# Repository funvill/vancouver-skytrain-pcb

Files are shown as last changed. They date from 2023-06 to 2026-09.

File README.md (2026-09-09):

# Vancouver SkyTrain PCB

A printed circuit board that is a map of Metro Vancouver's SkyTrain network,
with one addressable RGB LED per station. Based on
[Idea022 Translink Map PCB](https://blog.abluestar.com/idea022-translink-map-pcb/).

| Version | Where | What |
|---|---|---|
| **v3 (current)** | [`ai-v3/`](ai-v3/) | 200 × 109 mm board, real geography from the BC Freshwater Atlas, station positions from OpenStreetMap, 68 WS2812B LEDs (every current and under-construction station + SeaBus), XIAO controller footprint on the back, generated end-to-end from a data file |
| v2 | [`v2/`](v2/) | 100 × 83 mm schematic-style board, artwork drawn in Inkscape and imported with svg2shenzhen |
| v1 | [`v1/`](v1/) | 320 × 210 mm board with two LEDs per station (one per direction), ESP32 |

**Front** — exposed-copper water, silkscreen routes and station rings, one LED per station:

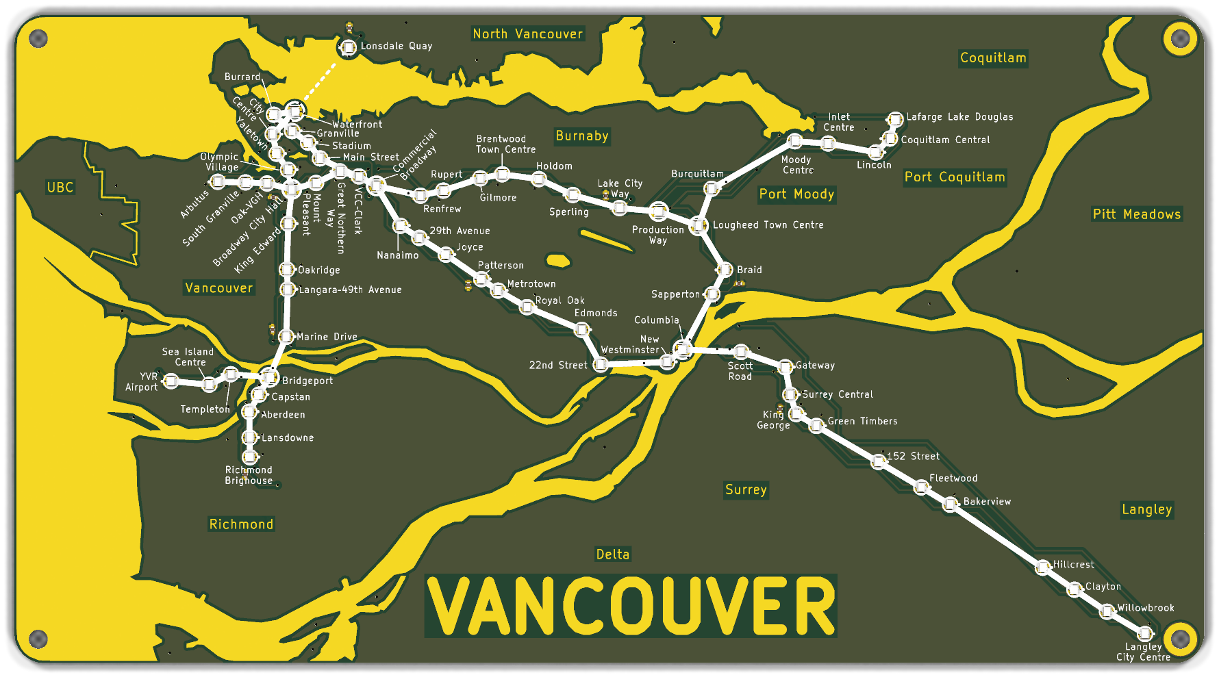
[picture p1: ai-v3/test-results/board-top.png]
v3 board, front


**Back** — XIAO controller footprint, four buttons, LED chain in/out test points, M3 mounting holes:

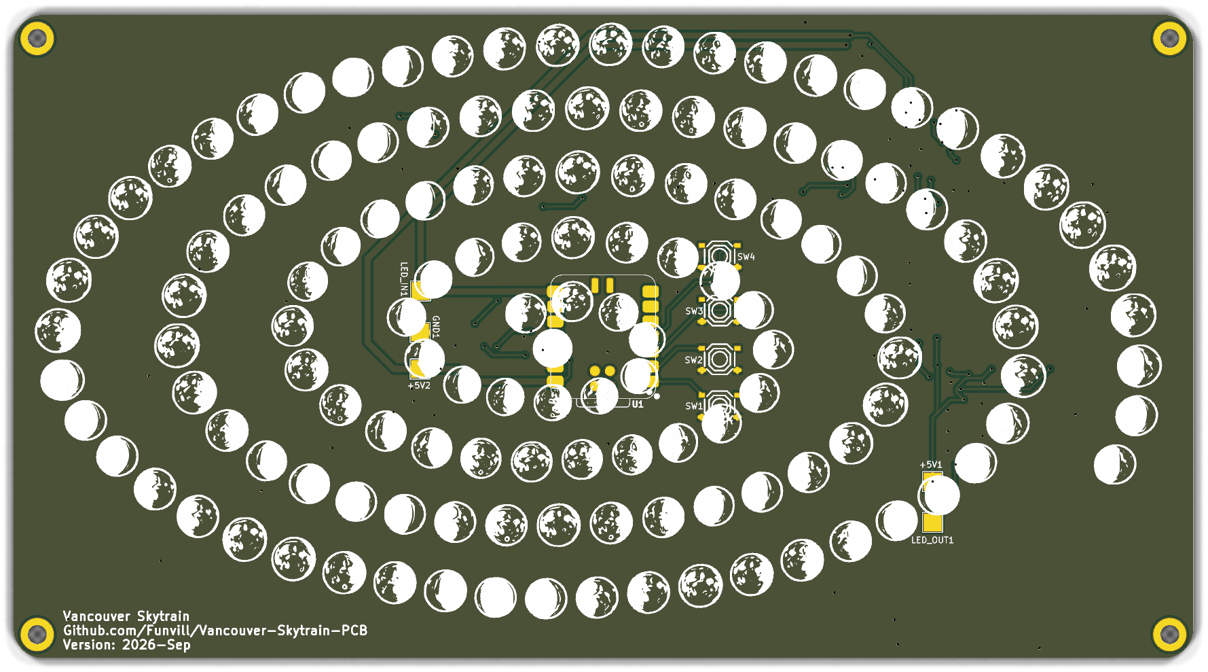
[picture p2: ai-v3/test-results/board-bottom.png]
v3 board, back


Renders are KiCad 10 `kicad-cli pcb render` output (`ai-v3/tools/render_board.py`); the
geography-only preview is `ai-v3/test-results/geo-preview.png`.

## v3 in one paragraph

Everything on the v3 board — LED placement, the exposed-copper water, the
silkscreen routes, station rings and labels, the copper city names and
wordmark — is generated from one data file, `ai-v3/input/vancouver.json`, by
the scripts in `ai-v3/tools/`. The data file is itself built from public
sources (`ai-v3/input/build_from_fwa.py`): the province's Freshwater Atlas
for land, sea, rivers and lakes; OpenStreetMap for station positions; the
province's ABMS layer for the UBC boundary. Labels are laid out by an
optimiser and then finished by hand in KiCad, and the hand edits are pulled
back into the data file so nothing is ever lost to a regeneration.

## Pipeline (v3)

All commands run from `ai-v3/tools/` unless noted. Python 3 with `shapely`,
`numpy`, `scipy`, `pillow`, `matplotlib`; KiCad 10 (its `kicad-cli` is used
for DRC and renders).

### 1. Data

```
cd ai-v3/input
python geo_fwa.py                 # (optional) preview the geography alone -> ../test-results/geo-preview.png
python build_from_fwa.py          # geography + stations + city labels + wordmark -> vancouver.json
cd ../tools
python test_vancouver_data.py     # LED count, chain, pitch, margins
```

`build_from_fwa.py` keeps every station's `label` and the `suppressed_art`
list, so it is safe to re-run after hand edits.

### 2. Labels

```
python auto_label.py                       # greedy placement + simulated annealing
python preview_map.py ../input/vancouver.json ../test-results/preview.png --collisions
python check_fit.py ../input/vancouver.json --scale 2.0 -v
```

`preview_map.py` draws the board exactly as the exporter will (matplotlib,
no KiCad); the red overlay marks collisions.

### 3. Board

```
python export_placement.py ../input/vancouver.json ../hardware --scale 2.0
python reposition_board.py ../hardware/vancouver-skytrain-pcb.kicad_pcb ../hardware/leds.csv --board 200 --height 109
python export_art.py ../input/vancouver.json ../hardware/vancouver-skytrain-pcb.kicad_pcb --scale 2.0
python render_board.py ../hardware/vancouver-skytrain-pcb.kicad_pcb ../test-results
```

`export_art.py` is idempotent: it records every block it writes (uuid → key)
in `vancouver-skytrain-pcb.kicad_pcb.art-manifest.json` and removes them
before writing fresh ones.

### 4. Hand edits in KiCad → back into the data (**import before export**)

Station labels, leader lines and copper text are ordinary `gr_text` /
`gr_line` items. Move, rotate, re-justify, retext or delete them in KiCad,
save, then:

```
python import_labels.py ../input/vancouver.json ../hardware/vancouver-skytrain-pcb.kicad_pcb
```

Each item is found by its deterministic uuid, so the import is exact:

| You did in KiCad | Lands in `vancouver.json` as |
|---|---|
| moved / rotated / re-justified a station label | `label.dx` `dy` `angle` `anchor` (`start` / `end` / `center`) |
| deleted a leader line | leader dropped (`leader` absent) |
| edited a label's text (line break, shorter name) | station `wrap` list, or `label.short` |
| moved a city name or the wordmark | `annotations[i].x` / `y` |
| deleted a piece of generated art (SeaBus dash, route segment, boundary) | key added to `suppressed_art`; the exporter skips it from then on |

**Always run `import_labels.py` before `export_art.py`** — the exporter
regenerates every label from the data file and would otherwise overwrite
the board's hand edits. `import → export` reproduces the board exactly.

## Lessons learned

See [lessons-learned.md](lessons-learned.md) — what to carry into the next
board of this kind, and the mistakes not to repeat.

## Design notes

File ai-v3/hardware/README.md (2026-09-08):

# v3 Hardware (KiCad)

Copied from the v2 project, then rewritten by the pipeline:

- **Board outline**: 150 × 150 mm, 5 mm rounded corners (was v2's 100 × 82.9 mm)
- **LED1–LED68**: moved to the station positions in `leds.csv` (generated from
  `ai-v3/input/vancouver.json` by `tools/export_placement.py`). LED index =
  ref − 1 = position in the data chain; LED1 is SeaBus, first after the shifter.
- **U1 (XIAO, back)**: centered at (75, 75); **SW1–SW4** flank it. All DNP.
- v2's stale svg2shenzhen art footprints were removed.
- **Station labels + land/water art** (F.SilkS text, F.Cu/F.Mask water,
  F.SilkS land outlines) generated directly into the board by
  `tools/export_art.py` — no Inkscape/svg2shenzhen step needed. See below.
- The coastline in `ai-v3/input/vancouver.json`'s `geo` list is hand-authored
  to resemble Vancouver's real geography (Burrard Inlet with the Port Moody
  arm, the downtown peninsula, False Creek between the Canada Line and
  Broadway corridor, the Fraser River's islands) at the level of detail v1's
  natural map used — not the coarse first-pass shapes from earlier in this
  project. Render `tools/render_board.py` output before touching `geo`
  again, so you're comparing against the current look, not an old shape.

**Render the board as images** (KiCad 9's built-in 3D renderer, top-down):

```
python render_board.py ../hardware/vancouver-skytrain-pcb.kicad_pcb ../test-results
```

Writes `board-top.png` and `board-bottom.png`. Pass `--kicad-cli` if
`kicad-cli.exe` isn't at the default `C:\Program Files\KiCad\9.0\bin\`.

Regenerate placements after any layout change:

```
cd ../input && python build_from_fwa.py      # geography + stations + city labels -> vancouver.json
cd ../tools
python export_placement.py ../input/vancouver.json ../hardware --scale 2.0
python reposition_board.py ../hardware/vancouver-skytrain-pcb.kicad_pcb ../hardware/leds.csv --board 200 --height 109
python export_art.py ../input/vancouver.json ../hardware/vancouver-skytrain-pcb.kicad_pcb --scale 2.0
```

The board is **200 × 109 mm** (`board_scale` 2.0 in `vancouver.json`: board mm =
canvas units × 2). Preview the layout without KiCad with
`python preview_map.py ../input/vancouver.json ../test-results/preview.png --collisions`.

**Hand-editing labels in KiCad.** Station labels, their leader lines and the
copper city names / wordmark are ordinary `gr_text` / `gr_line` items — move,
rotate, re-justify, retext or delete them in the PCB editor. Then pull the
edits back into the data file **before** the next `export_art.py` run (which
regenerates every label from `vancouver.json` and would otherwise overwrite
them):

```
python import_labels.py ../input/vancouver.json ../hardware/vancouver-skytrain-pcb.kicad_pcb
```

Each item is found by the deterministic uuid the exporter gave it, so the
import is exact: position/rotation/justification → `label.dx/dy/angle/anchor`,
a deleted leader line → `leader: false`, an edited text → the station's
`wrap` (or `label.short`), a moved city name → `annotations[i].x/y`. A
pre-edit copy of the board and data lives in `backups/` (and git tag
`v3-pre-label-edit`).

Run them in that order (placement first, art second — art positions itself
relative to the current LED footprint locations). `export_art.py` is
idempotent: it tracks every block it writes in
`vancouver-skytrain-pcb.kicad_pcb.art-manifest.json` and removes them before
writing fresh ones, so re-running after an edit to `vancouver.json` never
leaves stale or duplicated art behind.

## Station labels, route lines, and land/water art

`export_art.py` writes native KiCad graphics directly into the `.kicad_pcb`
(not through svg2shenzhen — that path is for hand-drawn art; ours is
generated straight from the same station/geo data as everything else),
styled after TransLink's own "Future Rapid Transit Network" map — one water
colour, filled parks, labelled rivers/municipalities, and a distinct look
for future/under-construction line segments:

- **Route lines** (`route_blocks`) — every line segment from
  `vancouver.json`'s `lines` as an F.SilkS `gr_line`, 1.0 mm wide. A segment
  with either endpoint `future: true` (Broadway Extension, Surrey–Langley
  Extension) is drawn as real **dashed segments** (`dash_points()`) instead
  of one solid line — matching the reference map's "future line" styling.
  Important: KiCad's `(stroke (type dash))` line-*style* property is an
  **editor display hint only** — it does not survive to plotted/fab output
  (SVG export, 3D render, gerbers all flatten it to solid), confirmed by
  testing both here. A genuinely dashed silkscreen line has to be built
  from literal short solid segments with real gaps, which is what
  `dash_points()` does.
- **Station names** — `gr_text` on F.SilkS, same position/rotation math as
  the SVG preview (`citymap.label_box`), 0.15 mm stroke at 1.2 mm. Names
  longer than 13 characters are set on **two lines** (split at the
  official en-dash, else at the middle space — `citymap.display_lines`;
  override per station with `"wrap": [...]` or `"wrap": false`), so the
  abbreviated `short` forms are no longer used on the board. Every label
  anchor sits `LABEL_STANDOFF` (1.9 mm) from the LED centre, clear of the
  pad and ring. A label with `"leader": true` is floated out to its dx/dy
  and joined to the LED by a 0.15 mm hairline — `auto_label.py` uses that
  as a last resort for stations with no clean spot beside the pad, and
  prefers one angle per corridor so the eye tracks a single direction.
- **Station rings** (`station_ring_blocks`) — a silk ring behind every LED
  (r 1.25) so the station reads as circle-on-line; interchanges (`
  "interchange": true`) get a heavier r 1.55 ring. Routes are 1.5 mm.
- **Map furniture** — `geo` entries of `"type": "line"` are plain silk
  polylines with an optional `"dash"` of `dash` / `dot` / `dashdot`
  (SeaBus ferry route, the 49th-parallel border, legend swatches); an
  annotation with `"copper": true` is exposed-copper lettering (F.Cu +
  F.Mask, the gold "VANCOUVER" wordmark from v2).
- **Water** (sea, False Creek, Fraser River) — a filled polygon on **F.Cu**
  with a matching filled polygon on **F.Mask**, so the soldermask opens
  over the copper and it reads as bare copper (gold with ENIG) against the
  black board — the same technique v1 used
  (`v1/input/natrual/natrual/map.kicad_pcb`), generated instead of
  hand-drawn.
- **Land — islands**: thin F.SilkS outline only, no fill (the board
  substrate itself *is* the land, so these just need a boundary).
  **Land — parks**: outline *plus* a 45° diagonal hatch fill
  (`citymap.hatch_fill()`, 1.6 mm spacing) — the single-ink silkscreen
  stand-in for the reference map's solid green park colour. `hatch_fill()`
  is a general scan-line polygon fill (even-odd rule, works on concave
  shapes) so it's reusable for any future city's parks too.
- **Annotations** (`annotation_blocks`) — small F.SilkS text (legend
  labels, CANADA / USA at the border) or copper text (the wordmark). No
  municipality names or water-body labels are printed, by request.

### Station positions and geography: OpenStreetMap

Station positions and `vancouver.json`'s water shapes come from
OpenStreetMap via `../input/build_from_osm.py` — real station nodes, the
real shoreline (smoothed), the Fraser and Pitt rivers, and the large
lakes. The board is **150 × 86.2 mm**, the aspect of the lat/lon frame
(Point Grey → Langley, North Shore → below Langley) at 3.1 mm/km; water
runs to the board edge (0.4 mm copper-to-edge, corners pulled inside
the 5 mm radius) — there is no border. Earlier revisions used
TransLink's schematic PDF and then v1's hand-drawn map; see
`../input/README.md`. Deliberately not literal:

- Runs whose real spacing is under the LED pitch (downtown, Richmond,
  Sea Island, Coquitlam) are spread outward along their own direction,
  then any remaining too-close pair is separated symmetrically. The
  pitch floor is **3.3 mm**: LED footprints rotate to aim DOUT at the
  next LED, and two diagonal neighbours' pads need that to keep 0.2 mm.
- A station the smoothing leaves inside water (a river-bank station) is
  nudged onto land, as the real map shows it; every LED then gets a
  2.2 mm clearance disk carved out of the copper water.
- The "VANCOUVER" wordmark is exposed-copper lettering placed on land
  (Delta), at the first candidate spot clear of water and track.

Routes are one solid 1.0 mm style for every segment, built or not.
- The Broadway Extension and Surrey–Langley Extension aren't on the
  current-network PDF (not built yet), so those 14 stations are
  extrapolated by continuing each real corridor's traced direction and
  spacing from its last real station.
- Every station's label **direction** (which side of the dot the name
  sits on) is hand-tuned in `vancouver.json`, not traced — the PDF gives
  dot positions, not a reusable label layout. Real station spacing is
  tight enough in a few spots (the airport branch, the Coquitlam bend,
  New Westminster/Columbia/22nd Street) that some labels sit close to a
  neighbour's dot or to the water fill; `check_fit.py` calls these out
  as `label-geo` (expected for coastal stations) vs. real overlaps
  (`label-label`/`label-dot`/`label-line`, hand-fixed one at a time).

### Keeping copper art DRC-clean: `citymap.prepared_geo`

A water/land shape sized for the map doesn't know where the LEDs are, so
raw coordinates from `vancouver.json` will happily overlap LED pads,
bridge the board edge, or trip solder-mask-bridge/clearance rules.
`citymap.prepared_geo(city, scale, avoid_pts)` fixes this once, and
`render_map.py`, `check_fit.py`, and `export_art.py` all call it — so the
SVG preview, the label-collision report, and the physical board always
agree:

1. `densify()` — long polygon edges get intermediate vertices (so a strait
   crossing an LED cluster mid-edge, not just at a vertex, still gets
   caught).
2. `repel()` — any vertex within `keepout` of an LED is pushed away from it.
3. `clamp_to_board()` — vertices are kept inset from the board edge (copper
   needs edge clearance even where the art is meant to visually "bleed" to
   the frame, like the coastline running to the top of the board).
4. `simplify()` (open shapes only, e.g. rivers) — collapses the extra
   densify() vertices back down once they're no longer needed, so a long
   straight run doesn't turn into dozens of tiny render segments.

For **rivers** specifically (drawn as a chain of rectangles, one per
polyline segment, since they have width but no fill), `export_art.py`
adds a final per-segment safety check
(`citymap.poly_point_min_dist`, `RIVER_SAFE_FLOOR`): any rectangle that
still ends up too close to an LED after all of the above is *dropped*
rather than emitted un-safe, and the drop is printed, not silent. On this
board the Fraser River crosses the same tight diagonal corridor the Expo
Line's SkyBridge stations occupy, so several of its segments are
intentionally omitted — the gaps read as the river passing under a
bridge, which is accurate. If you widen station spacing or move the river
line, re-run `export_art.py` and check its printed drop list.

**Known cosmetic-only DRC warnings** (verified non-blocking,
`kicad-cli pcb drc`, 2026-08-30): a handful of `silk_overlap` /
`silk_over_copper` warnings where a station label or a park/island
outline crosses the water fill or another silk element (e.g. Aberdeen's
label crossing the Lulu Island outline). These are `warning`-severity
(KiCad reports them as "Local override" candidates) and are the expected
look of a coastal transit map with exposed-copper water — no station near
the water was going to avoid overlapping it. `clearance` and
`copper_edge_clearance` (the categories that would actually risk a fab
reject or a short) are both **0** after the fixes above.

## Still manual (open in KiCad)

1. **Rotate LEDs for chain routing** — `leds.csv` has the suggested rotation
   (DOUT toward the next chain index); the script deliberately does not touch
   rotation because pad angles must be rewritten by KiCad itself.
2. **Verify U1 orientation**: USB-C must face the bottom board edge (Y+).
3. **Schematic**: v2's sheet is still the source. Confirm the 68-LED chain
   order matches `leds.csv`, add the **74AHC1G125** (C23654) data buffer at
   5 V + 330 Ω series R, decoupling (100 nF per 2 LEDs + 2 × 22 µF bulk), and
   re-annotate/re-sync with the board.
4. Route the data chain and power/ground pours (front + back).
5. DRC, then JLCPCB fab outputs (gerbers / BOM / CPL). Board finish: black
   soldermask, white silk, ENIG (so the exposed-copper water reads gold).

Pre-existing, not caused by the above (present since the v2 copy — schematic
has no routing yet): `unconnected_items`, `shorting_items` (unrouted nets),
`lib_footprint_mismatch` (library version drift), `courtyards_overlap`
(U1/button placement), one `text_height` warning on U1's hidden reference
field, and a `solder_mask_bridge` pair on nearly every LED footprint's own
pads (the XL-1615 library footprint's pads sit close together at that
package size — a library fix, not something the map art caused).

Firmware lives in `../firmware` (PlatformIO, XIAO RP2040, builds clean);
its index tables (`include/firmware_tables.h`) are generated by the same
export — regenerate both together.

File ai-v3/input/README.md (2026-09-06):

# Input data

- **`vancouver.json`** — the city data file the whole `ai-v3/tools/`
  pipeline reads (schema documented in `../docs/plan.md`).
- **`build_from_osm.py`** — **the current source of station positions and
  geography.** Builds `vancouver.json` from OpenStreetMap: real station
  nodes, the `natural=coastline` ways (land is on the left of a coastline
  way — that's how sea and land are told apart), the Fraser/Pitt river
  centrelines buffered where the coastline stops, and only the large
  named lakes (Burnaby, Deer, Trout, Como, Lost Lagoon…). The shoreline
  is smoothed (morphological open/close + simplify) so it reads clean at
  3 mm/km. The frame is a lat/lon box (Point Grey → past Langley, North
  Shore → below Langley) and the board takes its aspect: **150 × 86.2 mm**,
  water running to the board edge. Raw Overpass responses are cached in
  `osm/` (queries listed at the bottom of the script) so it runs offline.
  Run it, then `../tools/auto_label.py`, then the hardware pipeline with
  `reposition_board.py --board 150 --height 86.2`.
- `build_from_v1.py` — superseded: built the map from the v1 project's
  hand-drawn natural map, kept for reference (its `v1_*.json` inputs too).
- **`skytrain-network-map.pdf`** — TransLink's official current-network
  map. It was the tracing source for an earlier revision (below); its
  schematic page is 1.26:1 where the real region is ~2:1, so everything
  south of Broadway came out stretched and the Fraser turned into a
  45° band — which is why the v1 natural map replaced it.

## (Superseded) How `vancouver.json` was traced from the PDF

Station positions and land/water/park shapes are **not hand-drawn** — they
were extracted from the PDF's actual vector content (text + path data),
not eyeballed from a rendered image. Rerun this pipeline after swapping in
a newer PDF (a future TransLink map revision, or the Broadway/Surrey–Langley
version once it exists):

```
pip install pdfplumber pymupdf shapely   # one-time
python match_stations.py     # words.json + circles.json -> station_coords.json
python build_geo.py          # geo_shapes.json -> geo_canvas.json (water/park polygons)
python build_vancouver_json.py   # writes ../input/vancouver.json
```

1. **`match_stations.py`** — `pdfplumber` extracts every text label's exact
   (x, y); `pymupdf` (`fitz`) extracts every station-dot circle (drawn as a
   small filled circle, colour-coded by line — teal `(0,0.61,0.78)` =
   Canada Line, medium blue `(0,0.37,0.67)` = Expo Line, yellow
   `(1,0.83,0)` = Millennium Line, navy `(0,0.21,0.37)` = an
   interchange/major-hub marker). Each station gets one reliable,
   document-unique anchor word (`ANCHOR` in `match_stations.py`) and is
   matched to its nearest circle. Diagonal/angled labels near line
   junctions (Commercial–Broadway, Lougheed Town Centre, Sapperton, Lake
   City Way, VCC–Clark…) came out as garbled individual characters from
   pdfplumber (the angled text confuses its word-grouping) — those were
   resolved by hand against the known real line topology (station order,
   even spacing along a row/diagonal) instead of by text matching; see
   `build_vancouver_json.py`'s `PDF_XY` table for the final values used.
2. **`build_geo.py`** — the PDF draws land as opaque cream polygons over a
   full-page water-blue background, the opposite of our board (water is
   the explicit exposed-copper shape, land is just the bare board). This
   script extracts every land polygon's vector points, unions them with
   Shapely, and subtracts that union from the page rectangle — the
   remainder *is* the water, matching the PDF exactly, including the
   Fraser's arms and Sea Island / Lulu Island falling out as holes
   automatically (no river/island shape was hand-drawn or guessed).
   Park polygons are extracted the same way and kept separate for the
   hatch-fill treatment.
3. **`build_vancouver_json.py`** — converts every PDF-point coordinate to
   the 0–100 canvas with a uniform affine transform (a fixed margin inset
   + independent-axis scale to fill the square board — the real network
   is wider than it is tall, so this is the one deliberate distortion;
   everything else preserves the source proportions exactly). The Broadway
   Extension and Surrey–Langley Extension stations aren't on this PDF (not
   built yet) — they're extrapolated by continuing each real corridor's
   traced direction and spacing from its last real station, not traced
   from a source.
4. Label **angle/anchor** (which side of the dot the name sits on) still
   has to be tuned per station in `vancouver.json` afterward — the PDF
   trace gives the *dot* position, not a usable label layout, since the
   official map's real labels are hand-placed by a cartographer and
   pdfplumber's per-character extraction for angled ones isn't reliable
   enough to reuse directly. `../tools/auto_label.py` automates this: it
   brute-forces every angle in `[-90, 90]` (angles outside that range
   render the glyphs upside-down/mirrored in KiCad — rotation is rigid,
   there's no auto-flip for readability) crossed with `start`/`end`
   anchor for each station `check_fit.py` flags a real collision on
   (`label-label`/`label-dot`/`label-line` — not `label-geo`, which is
   expected for a station that's genuinely next to water or a park), and
   keeps the option with the fewest collisions. Re-run it after any
   position change; `check_fit.py -v` on its own shows what's left.

`words.json` / `circles.json` / `geo_shapes.json` / `geo_canvas.json` /
`station_coords.json` are the intermediate extraction artifacts (kept for
inspection/debugging) — none of them are hand-authored, and none should be
edited directly; edit `vancouver.json` instead, or rerun the pipeline
against a new PDF.

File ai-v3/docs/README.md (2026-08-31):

# Vancouver SkyTrain PCB — Version 3 (ai-v3)

Documentation for the third revision of the SkyTrain LED map PCB.

## Goal for v3

A **smaller, square board** showing the **iconic (schematic-style) SkyTrain map**, with:

- The same WS2812B addressable RGB LEDs used in v2 (XL-1615RGBC-WS2812B-1, LCSC C5349954)
- One LED per station, including **all new and under-construction stations**
  (Capstan, the Broadway Extension, and the Surrey–Langley Extension)
- **No controller populated on the board.** Instead, a Seeed Studio **XIAO footprint on the
  back** of the board so any XIAO-family module (RP2040, ESP32-C3, SAMD21, nRF52840…) can be
  soldered on.

## Documents

| File | Contents |
|---|---|
| [project-review.md](project-review.md) | Review of v1 and v2 in their current state — what was built, what works, what's unfinished |
| [v3-recommendations.md](v3-recommendations.md) | Recommendations and a step-by-step plan for building v3 |
| [station-list.md](station-list.md) | Complete station list (including future stations), interchange notes, and a proposed LED chain order |
| [plan.md](plan.md) | Implementation plan (assumption tests → board → firmware → reusable pipeline) |
| [fit-report.md](fit-report.md) | Results of the 100 mm text-fit test — verdict: 135 × 135 mm recommended |

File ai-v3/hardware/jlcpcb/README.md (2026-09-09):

# JLCPCB outputs

Generated from `vancouver-skytrain-pcb.kicad_pcb` / `.kicad_sch` with KiCad 10
`kicad-cli` (see the commands at the bottom). Regenerate after any board change.

| File | Upload as |
|---|---|
| `vancouver-skytrain-pcb-gerbers.zip` | **Gerber file** on the order page — 9 layers (F/B Cu, Paste, Mask, Silk + Edge.Cuts, Protel extensions), Excellon drill `.drl` (PTH + NPTH merged) and the drill map |
| `bom-jlcpcb.csv` | **BOM** on the SMT assembly page — `Comment, Designator, Footprint, LCSC Part #` |
| `cpl-jlcpcb.csv` | **CPL / pick-and-place** — `Designator, Mid X, Mid Y, Layer, Rotation` (mm, KiCad position-file convention) |

Assembly covers the **68 WS2812B LEDs** (C5349954, top side) and the **8 × 10 µF
0402 capacitors** (C52923). Everything else is not placed by JLC:

- **SW1–SW4** are DNP in the schematic.
- **U1** (Seeed XIAO) is a module soldered by hand.
- Test points and mounting holes have no part.

`pos-raw.csv` and `bom-raw.csv` are the untouched `kicad-cli` outputs the two
JLC files were derived from.

**Check on the JLC page before ordering:** the LED rotation. JLC's part
library orientation for C5349954 may differ from the KiCad footprint's by a
constant; the placement preview shows pin 1 — if every LED is off by the same
angle, correct the `Rotation` column by that constant (all LEDs share the
same footprint, so one offset fixes all 68).

Board: 200 × 109 mm, 2 layers, ENIG recommended (the exposed-copper water is
the artwork — HASL works but reads silver), any soldermask colour; the design
was previewed in dark green with white silkscreen.

```
kicad-cli pcb export gerbers vancouver-skytrain-pcb.kicad_pcb -o jlcpcb/gerbers/ \
    -l F.Cu,B.Cu,F.Paste,B.Paste,F.SilkS,B.SilkS,F.Mask,B.Mask,Edge.Cuts \
    --subtract-soldermask --no-x2 --no-netlist --check-zones
kicad-cli pcb export drill vancouver-skytrain-pcb.kicad_pcb -o jlcpcb/gerbers/ \
    --format excellon --excellon-units mm --generate-map --map-format gerberx2
kicad-cli pcb export pos vancouver-skytrain-pcb.kicad_pcb -o jlcpcb/pos-raw.csv \
    --format csv --units mm --side both --exclude-dnp
kicad-cli sch export bom vancouver-skytrain-pcb.kicad_sch -o jlcpcb/bom-raw.csv \
    --fields "Reference,Value,Footprint,LCSC Part,LCSC,DNP" --group-by "Value,Footprint,LCSC Part,LCSC" --exclude-dnp
python ../tools/make_jlcpcb.py      # -> bom-jlcpcb.csv, cpl-jlcpcb.csv, gerbers zip
```

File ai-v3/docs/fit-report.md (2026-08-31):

# V3 Text-Fit Test Report

**Question:** does the iconic map with all 68 station names fit on a 100 × 100 mm board?

**Answer: No — as expected. Full station names need ≥ 120 mm.**

> **DECISION (user, 2026-08-30): board is 150 × 150 mm**, map extended west to cover the
> Point Grey peninsula. The layout was re-tuned for 150 mm (network shifted 5 mm east for
> the peninsula, Surrey leg turns south at Bakerview, Coquitlam branch stepped down-left)
> and now checks **0 collisions with full names at 1.2 mm text**. Geography added: sea
> outline (Burrard Inlet + Port Moody arm + English Bay + Georgia Strait), False Creek,
> Fraser River, Sea Island and Lulu Island outlines, and parks (Stanley, Pacific Spirit,
> Queen Elizabeth, Central, Green Timbers, Burnaby Lake, Lafarge Lake).
> On the physical board: water = soldermask-opening or copper-pour treatment, parks =
> silkscreen hatch — final layer mapping is chosen in the artwork-export task.

## Method

The reusable pipeline (`ai-v3/tools/`) models every station label as a rotated rectangle
(char width = 0.7 × text height, KiCad-stroke-font-like metrics) and counts collisions:
label↔label, label↔route-line, label↔LED-dot, and label-off-board. Board size scales;
text height does not (silkscreen has a fab minimum), which is exactly why bigger boards
fix text crowding. Reference silkscreen heights: **1.0 mm = JLCPCB minimum**, **1.2 mm =
comfortably readable**.

Layout under test: `ai-v3/input/vancouver.json` — 67 stations + SeaBus = 68 LEDs,
octilinear iconic geometry, validated by `test_vancouver_data.py` (counts, shared
interchanges, 45°/90° segments, ≥ 2.5 mm LED spacing).

## Results (collision counts, lower = better)

| Board | 1.0 mm full | 1.0 mm short | 1.2 mm full | 1.2 mm short |
|---|---|---|---|---|
| 100 mm | 5 | 1 | **16** | 4 |
| 120 mm | **0** | 0 | 4 | 1 |
| 135 mm | 0 | 0 | **1** | 0 |
| 150 mm | 0 | 0 | 0 | 0 |

Rendered previews (collisions highlighted red): `ai-v3/test-results/map-*.svg`,
back side: `ai-v3/test-results/back-side.svg`.

## Findings

1. **100 mm fails for full names.** At readable text (1.2 mm) there are 16 collisions and
   five labels run off the board (Coquitlam Central, Vancouver City Centre, Oakridge,
   Sea Island Centre, YVR). The user's expectation that the board must grow is confirmed.
2. **Label geometry matters as much as board size.** The first layout iteration had
   collisions that *no* board size fixed (labels crossing a parallel line 3 mm away scale
   with the board, staying in collision). Fix that worked: move the **Canada Line from
   x=16 → x=19 mm** so the west-Broadway diagonal labels clear it, put King Edward's and
   Broadway–City Hall's labels on the south-east diagonal, and anchor the airport-branch
   labels to the left. After that, collisions became purely text-size-vs-board-size.
   *Lesson encoded for future cities: keep ≥ 7 mm between a vertical line and any station
   to its west whose label points down-right.*
3. **120 mm works at fab-minimum text** (1.0 mm, full names, zero collisions) but 1.0 mm
   white-on-black silk is squint territory.
4. **135 mm works at comfortable text** (1.2 mm) with a single residual collision:
   "29th Avenue" clips the tail of "Great Northern Way–Emily Carr" (the longest name on
   the network, 29 chars ≈ 24 mm of silk). Using its short form "Gt Northern Way" — or a
   future two-line label feature — clears it: **zero collisions**.
5. **150 mm is fully clean** with all full names at 1.2 mm.
6. **Back side is a non-issue at any size.** XIAO SMD courtyard (19.8 × 23 mm incl.
   margin) centered with USB-C toward the bottom edge, 4 × 5.1 mm buttons, 74AHC1G125 and
   bulk caps all fit with huge margins on even the 100 mm board. The board is all-SMD, so
   front LEDs and back parts can overlap in Z with no conflict; only via placement needs
   care during routing. USB-C sits ~57 mm from the bottom edge on a 135 mm board — a
   cable reaches it fine for desk use; for wall mounting, a keyhole slot must avoid the
   board center.

## Recommendation

- **Board: 135 × 135 mm**, text 1.2 mm, full names everywhere except
  "Gt Northern Way" (short form). Nicely, `v2/input/map3.svg` was already drawn at
  150 × 150 — the artwork tradition supports a board in this class, and 135 mm keeps it a
  step smaller while staying collision-free.
- Fallback if cost matters: 120 × 120 mm with 1.0 mm text (JLC minimum) — fits, but
  print a paper mockup first to judge readability.
- 100 × 100 mm remains viable only as a "dots + interchange names" novelty variant; the
  data file already carries `short` names if that route is ever wanted.

## Assumptions verified / still open

| Assumption | Status |
|---|---|
| 68 LEDs (67 stations + SeaBus) covers the full 2029 network | ✔ verified by data test (counts + interchange dedupe) |
| Iconic octilinear layout fits a square canvas | ✔ rendered, visually recognizable as the SkyTrain map |
| 100 mm too small for names | ✔ confirmed (16 collisions @ 1.2 mm) |
| ≥ 2.5 mm LED-to-LED spacing everywhere | ✔ min pitch 3.0 mm (Sapperton–Braid) |
| XIAO + buttons + shifter fit on back | ✔ trivially |
| Land/water geometry co-exists with map | ✔ rendered (inlet, False Creek, Fraser, Sea Island); final art treatment (mask openings vs. silk) still to be chosen |
| Fab: 1.2 mm text / 0.15 mm stroke OK for JLC white silk | ⚠ to confirm against JLC capabilities page at order time |
| Surrey–Langley station names final | ⚠ working names — re-verify before silk |

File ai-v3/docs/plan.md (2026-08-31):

# SkyTrain PCB v3 Implementation Plan

> **For agentic workers:** REQUIRED SUB-SKILL: Use superpowers:subagent-driven-development (recommended) or superpowers:executing-plans to implement this plan task-by-task. Steps use checkbox (`- [ ]`) syntax for tracking.

**Goal:** A 100 × 100 mm (size to be confirmed by the text-fit test) square PCB of the iconic Vancouver SkyTrain map — one WS2812B per station including all future stations, XIAO footprint (DNP) centered on the back with USB-C down, level shifter, SeaBus LED, iconic land/water geometry, white silkscreen on black soldermask.

**Architecture:** A city-agnostic Python pipeline (`ai-v3/tools/`) turns a per-city data file (`ai-v3/input/vancouver.json` — lines, stations, coordinates, geography) into (a) rendered SVG previews with collision/fit reports, (b) svg2shenzhen-ready artwork layers, and (c) LED placement + firmware index tables. The KiCad board consumes the pipeline output. The pipeline is the reusable component for future cities; only the JSON data file is city-specific.

**Tech Stack:** Python 3 (stdlib only — no pip deps, so it runs anywhere), SVG, KiCad 8, svg2shenzhen (Inkscape extension), PlatformIO + FastLED.

## Global Constraints

- Board: square, starting hypothesis **100 × 100 mm**; expand only if the text-fit test proves names don't fit (test heights: 1.0 mm fab minimum, 1.2 mm comfortable).
- Finish: **white silkscreen on black soldermask** (black board). Route lines rendered as silkscreen and/or exposed copper; art must read in white-on-black.
- LEDs: **XL-1615RGBC-WS2812B-1 (LCSC C5349954)**, one per station, plus **1 SeaBus LED** — **68 LEDs total** (67 unique stations + SeaBus).
- Stations: full 2029 network — Expo 32 (incl. 8 Surrey–Langley, ~2029), Millennium 23 (incl. 6 Broadway Extension, ~2027), Canada 17 (incl. Capstan), minus 5 shared interchange stations.
- Controller: **no controller populated**. Seeed **XIAO SMD footprint on the back, DNP, centered, USB-C pointing down** (toward the bottom board edge). Buttons also on back, **DNP**.
- Level shifter: **74AHC1G125** (SOT-23-5, LCSC C23654) on the LED data line, powered at 5 V, as in v1.
- Geography: iconic land/water shapes (Burrard Inlet, downtown peninsula, Fraser River, Sea Island) on the artwork layers.
- Reusability: tools must not hard-code Vancouver anything; all city data lives in the input JSON.

---

## Phase A — Assumption tests (before any board work)

### Task 1: City data schema + Vancouver data file

**Files:**
- Create: `ai-v3/input/vancouver.json`
- Create: `ai-v3/tools/citymap.py` (shared loader/model)
- Test: `ai-v3/tools/test_vancouver_data.py`

**Interfaces:**
- Produces: `citymap.load(path) -> City` where `City` has `.stations` (dict id → Station with `name, short, x, y, future, label` fields), `.lines` (list of Line with `id, name, color, paths` = lists of station ids), `.extras` (SeaBus), `.geo` (water/land polygons), `.canvas_mm`.
- JSON schema (city-agnostic):

```json
{
  "city": "vancouver",
  "canvas_mm": 100,
  "lines": [
    {"id": "expo", "name": "Expo Line", "color": "#005DAA",
     "paths": [["waterfront", "burrard", "..."], ["columbia", "scott-road", "..."]]}
  ],
  "stations": {
    "waterfront": {"name": "Waterfront", "x": 16, "y": 10,
                    "label": {"angle": 0, "anchor": "end"}, "future": false}
  },
  "extras": [{"id": "seabus", "name": "SeaBus", "x": 20, "y": 5}],
  "geo": [{"name": "burrard-inlet", "type": "water", "points": [[0,0], [100,0], "..."]}]
}
```

- [ ] **Step 1: Write failing validation test** (`test_vancouver_data.py`): 68 LEDs total (stations + extras); every path id resolves; the 5 interchange stations appear in ≥ 2 lines but exist once; every consecutive station pair is octilinear (horizontal, vertical, or 45°); all coordinates within canvas with ≥ 3 mm margin; every station has a non-empty name.
- [ ] **Step 2: Run it** — fails (no data file).
- [ ] **Step 3: Author `vancouver.json`** — all 67 stations + SeaBus with iconic octilinear coordinates on a 100 mm canvas, per-station label angle/anchor, `short` names for long stations, geography polygons.
- [ ] **Step 4: Run test — passes.**
- [ ] **Step 5: Commit** (`git -c user.name="SWS-Chipkin" -c user.email="sws-dev@chipkin.com" commit`).

### Task 2: SVG renderer

**Files:**
- Create: `ai-v3/tools/render_map.py`
- Test: rendered output inspected + self-checks in `test_vancouver_data.py` extended

**Interfaces:**
- Consumes: `citymap.load()`.
- Produces: `render(city, scale=1.0, text_h=1.2, use_short=False) -> str (svg)`; CLI `python render_map.py vancouver.json out.svg --scale 1.0 --text 1.2`.
- SVG in mm units: black board rect, water polygons, route polylines (line colors for preview; final art is white), station dots + 1.6 × 1.5 mm LED body outline, rotated labels, XIAO 17.8 × 21 mm outline centered (back-side ghost), board outline.

- [ ] **Step 1:** Implement renderer.
- [ ] **Step 2:** Render at scale 1.0 and view in browser — layout is recognizable as the SkyTrain map, no gross errors.
- [ ] **Step 3:** Commit.

### Task 3: Fit checker (the actual assumption test)

**Files:**
- Create: `ai-v3/tools/check_fit.py`
- Output: `ai-v3/test-results/fit-report.md`, `ai-v3/test-results/map-*.svg`

**Interfaces:**
- Consumes: `citymap.load()`, same geometry code as renderer.
- Produces: `check(city, scale, text_h, use_short) -> FitResult(collisions: list, board_mm: float)`; label boxes modeled as rotated rectangles (char width = 0.7 × height + stroke), collision = label∩label, label∩other-line, label∩other-dot via SAT polygon intersection.

- [ ] **Step 1:** Unit test SAT intersection with two known rects (overlap / no overlap).
- [ ] **Step 2:** Implement checker.
- [ ] **Step 3:** Run the experiment matrix: {100 mm, 120 mm, 135 mm, 150 mm} × {1.0, 1.2 mm text} × {full, short names}. Record collision counts.
- [ ] **Step 4:** Write `fit-report.md` with the matrix, the verdict on 100 mm, and the recommended board size. Render an annotated SVG (collisions highlighted red) for the chosen candidates.
- [ ] **Step 5:** Commit.

### Task 4: Back-side fit check (XIAO + buttons + level shifter)

**Files:**
- Modify: `ai-v3/tools/render_map.py` (back-side view mode)
- Output: `ai-v3/test-results/back-side.svg`

- [ ] **Step 1:** Render back view: XIAO-SMD courtyard (17.8 × 21 mm + 1 mm) centered, USB-C edge toward board bottom, 4 button courtyards (5.1 × 5.1 mm), 74AHC1G125, bulk caps; confirm no conflict with front LED thru-hole-free zone (all SMD, so only via keepouts matter).
- [ ] **Step 2:** Note reset/boot access and USB-C cable clearance in the report.
- [ ] **Step 3:** Commit.

**Decision gate:** present fit-report to the user; board size is locked here.

---

## Phase B — Board (after size is locked)

### Task 5: Pipeline outputs for KiCad

**Files:**
- Create: `ai-v3/tools/export_placement.py` — emits `leds.csv` (ref, x, y, rotation, station id) with chain order = the station-list order; emits `firmware_tables.h` (per-line index arrays) from the same data.
- Create: `ai-v3/tools/export_art.py` — emits svg2shenzhen-layered SVG (`Edge.Cuts`, `F.SilkS` = names + land outlines in white, `F.Mask` openings for copper route lines, `B.SilkS` credits block).
- Test: round-trip check — 68 rows in `leds.csv`, chain neighbors ≤ 25 mm apart (data-line routing sanity).

### Task 6: KiCad project

- Copy v2 KiCad project to `ai-v3/hardware/`; keep local libs (`C5349954-led`, `Seeed Studio XIAO`, `C318884-button`).
- Schematic: 68 LEDs chained, 74AHC1G125 buffer (input from XIAO D-pin, OE tied active, 5 V supply), 330 Ω series R at buffer output, 1 × 100 nF per 2 LEDs + 2 × 22 µF bulk, XIAO symbol (DNP), 4 buttons (DNP) to XIAO GPIOs with no external pull-ups (internal), SeaBus LED last in chain.
- Import `leds.csv` positions (KiCad "Position from file" / pcbnew script), import art via svg2shenzhen, place XIAO centered on B.Cu USB-C down, route 5 V/GND pours front+back, route data chain.
- DRC clean; JLCPCB production files (gerbers, BOM, CPL) with black soldermask + white silk + ENIG selected.

### Task 7: Firmware

- Copy `v1/firmware` → `ai-v3/firmware`; `platformio.ini`: `board = seeed_xiao_rp2040`.
- Replace index tables with generated `firmware_tables.h`; `NUM_LEDS = 68`; add `FastLED.setMaxPowerInVoltsAndMilliamps(5, 1500)`; keep demo animation; buttons on internal pull-ups for mode/brightness.
- Build passes; (bench test after boards arrive).

### Task 8: Reusable-pipeline extraction (after Vancouver ships)

- Move `ai-v3/tools/` to repo-root `tools/` (or its own repo) unchanged; document the JSON schema in `tools/README.md`; prove reuse by drafting a second city data file stub.

## Self-Review notes

- Spec coverage: 100 mm test (Task 3), expansion expectation (Task 3 matrix), new lines (Task 1 data), one LED/station (Task 1 test), XIAO back/DNP/centered/USB-down (Tasks 4, 6), buttons DNP (Tasks 4, 6), SeaBus (Task 1), level shifter (Task 6), land geometry (Tasks 1, 2, 5), white-on-black (Tasks 2, 5, 6), reusable components (schema-driven tools, Task 8). ✔
- Types consistent: `citymap.City` consumed by render/check/export. ✔

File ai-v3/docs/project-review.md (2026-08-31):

# Project Review — state as of 2026-08-30

Review of the repository (`vancouver-skytrain-pcb`) before starting version 3.

## Repository layout

```
v1/       Shipped first version (Teardown 2024 era). Hardware + firmware + inputs.
v2/       In-progress second version. Hardware + input SVGs. No firmware folder.
ai-v3/    New — empty except for these docs.
```

Uncommitted work: `v2/input/map3.svg` has significant local changes (+460 lines) that are
not committed. This appears to be the in-progress **150 × 150 mm square iconic map**
drawing and is directly relevant to v3 — it should be committed (or moved into `ai-v3/input/`)
before it gets lost.

---

## V1 — shipped board

**Hardware** (`v1/hardware/vancouver-skytrain-pcb/`, KiCad 8):

- Realistic/geographic map style ("natural"), rounded-rectangle board.
- **127 × XL-1010RGBC-WS2812B** (1.0 × 1.0 mm addressable RGB, LCSC C5349953) — one LED
  *per station per travel direction* (e.g. "Waterfront north" and "Waterfront south" are
  separate LEDs), which is why the count is roughly double the station count. Index 126 is
  the SeaBus.
- **On-board controller: ESP32-WROOM-32E** with 3.3 V LDO (UR133AG), a **74AHC1G125**
  buffer used as the 5 V level shifter for the LED data line, reset/boot buttons, Phoenix
  screw-terminal power input, and a programming header.
- 136 × 1 µF 0402 decoupling caps — essentially one per LED.
- Fun detail worth keeping: 126 test points shaped like bugs, one per LED.

**Firmware** (`v1/firmware/vancouver-skytrain/`, PlatformIO + FastLED):

- Demo mode written for Teardown 2024: multiple "trains" per line advance station-by-station
  with fading, per-line speeds. Lines covered: Expo (both directions, both branches),
  Millennium (both directions, **already includes the six Broadway Extension stations**
  through Arbutus), Canada Line (both directions, both branches), SeaBus.
- Note: `platformio.ini` targets **Raspberry Pi Pico** (`board = pico`), not the ESP32 that
  is on the v1 board. So the firmware in the repo as-is was last built for an RP2040 — this
  is actually convenient for v3 if a XIAO RP2040 is used (same chip family, same FastLED
  setup, just change the board to `seeed_xiao_rp2040`).
- Hard-coded LED-index-to-station tables. `NUM_LEDS = 130`, brightness capped at 32/255.

**What v1 proves:** the svg2shenzhen art pipeline works, the WS2812B chain at ~127 LEDs
works, the demo animation works, and JLC production files (BOM/CPL/gerbers) were generated
successfully.

---

## V2 — in progress

**Hardware** (`v2/hardware/`, KiCad):

- Board outline: **100 × 82.9 mm** rounded rectangle (not square).
- **68 × XL-1615RGBC-WS2812B-1** (1.6 × 1.5 mm, LCSC C5349954) placed — the larger 1615
  package instead of v1's tiny 1010. One LED **per station** this time (68 ≈ 67 unique
  future-network stations + SeaBus — see [station-list.md](station-list.md)).
- **Seeed Studio XIAO RP2040 footprint (SMD variant) already placed on the back (B.Cu)** —
  v2 already adopted the "no on-board controller, XIAO on the back" architecture that v3
  wants. Local libraries exist for XIAO RP2040 and SAMD21, in both DIP and SMD variants.
- 4 push buttons (C318884), 7 × 0402 caps, 5 test points, logos.
- Schematic exists (`vancouver-skytrain-pcb.kicad_sch`).
- Last commit: "part placement" (Nov 2025). No routing/production files yet, no firmware
  folder.

**Inputs** (`v2/input/`):

- `transitmap.svg` — stylized iconic map with 68 station circles (novelty styling, "$0.25"
  fare marks, "VANCOUVER" title).
- `map3.svg` — **150 × 150 mm square** drawing with proper svg2shenzhen layers
  (`Edge.Cuts`, `F.Cu`, `F.Mask`, `F.SilkS`, `B.SilkS`) plus a `station.names` layer, 68
  station markers. **Uncommitted local changes.** This is effectively the starting point
  for v3's artwork.

**What's missing in v2:** power/decoupling design is thin (7 caps for 68 LEDs vs. one-per-LED
in v1), no level-shifter decision recorded, board is not square, no routing, no firmware, and
the newest map work is uncommitted.

---

## Key observations going into v3

1. **v2 already made the two big architectural decisions v3 asks for** — one LED per
   station and a XIAO footprint on the back. v3 is best treated as *finishing v2 on a
   smaller square outline*, not a from-scratch redesign.
2. **The LED part decision is effectively made**: XL-1615RGBC-WS2812B-1 (C5349954), with
   library, 3D model, and 68 placements already in v2. "Same LEDs" should mean this part.
   (v1's 1010 part is fiddlier to hand-rework and gains nothing here.)
3. **The station data already exists twice** — in v1 firmware tables and in the v2 SVG
   markers — but nowhere as a single authoritative list. v3 should create one (see
   [station-list.md](station-list.md)) and generate both the firmware table and the LED
   placement from it.
4. **The firmware is 90 % reusable.** Change the board target to the XIAO, drop from
   two-LEDs-per-station to one, renumber the index tables, and the Teardown demo runs on v3.
5. **Two known electrical gaps to close** (both solved in v1, dropped in v2): LED data-line
   level shifting from a 3.3 V microcontroller to 5 V LEDs, and per-LED (or per-group)
   decoupling.

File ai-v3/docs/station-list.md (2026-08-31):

# Station List & Proposed LED Chain — v3

One LED per unique station. Network as of 2026 **plus stations under construction**:
Capstan (opened Dec 2024), the Broadway Extension (6 stations, ~2027), and the
Surrey–Langley Extension (8 stations, ~2029).

**Totals:** Expo 32 + Millennium 23 + Canada 17 = 72 line-stations − 5 shared
(Commercial–Broadway, Lougheed Town Centre, Production Way–University, Waterfront,
Broadway–City Hall) = **67 unique stations**, + 1 SeaBus marker = **68 LEDs**.
This matches the 68 markers already drawn in `v2/input/map3.svg`.

Chain order below is a proposal: contiguous per line, so firmware tables are simple ranges.
Interchange LEDs are owned by the first line that reaches them; later lines reference the
existing index (marked ↩).

## Expo Line (LED 0–31)

| LED | Station | Notes |
|-----|---|---|
| 0 | Waterfront | Interchange: Canada Line, SeaBus |
| 1 | Burrard | |
| 2 | Granville | |
| 3 | Stadium–Chinatown | |
| 4 | Main Street–Science World | |
| 5 | Commercial–Broadway | Interchange: Millennium |
| 6 | Nanaimo | |
| 7 | 29th Avenue | |
| 8 | Joyce–Collingwood | |
| 9 | Patterson | |
| 10 | Metrotown | |
| 11 | Royal Oak | |
| 12 | Edmonds | |
| 13 | 22nd Street | |
| 14 | New Westminster | |
| 15 | Columbia | Branch point |
| 16 | Sapperton | Production Way branch |
| 17 | Braid | |
| 18 | Lougheed Town Centre | Interchange: Millennium |
| 19 | Production Way–University | Interchange: Millennium |
| 20 | Scott Road | King George branch |
| 21 | Gateway | |
| 22 | Surrey Central | |
| 23 | King George | |
| 24 | Green Timbers | **Future (Surrey–Langley, ~2029)** |
| 25 | 152 St | **Future** |
| 26 | Fleetwood | **Future** |
| 27 | Bakerview–166 St | **Future** |
| 28 | Hillcrest–184 St | **Future** |
| 29 | Clayton | **Future** |
| 30 | Willowbrook | **Future** |
| 31 | Langley City Centre | **Future** |

## Millennium Line (LED 32–49, + 5 shared/↩)

| LED | Station | Notes |
|-----|---|---|
| 32 | Arbutus | **Future (Broadway Ext., ~2027)** — western terminus |
| 33 | South Granville | **Future** |
| 34 | Oak–VGH | **Future** |
| 35 | Broadway–City Hall | **Future on Millennium**; interchange: Canada Line (LED shared, owned here or by Canada — pick one) |
| 36 | Mount Pleasant | **Future** |
| 37 | Great Northern Way–Emily Carr | **Future** |
| 38 | VCC–Clark | Current western terminus |
| ↩ 5 | Commercial–Broadway | shared with Expo |
| 39 | Renfrew | |
| 40 | Rupert | |
| 41 | Gilmore | |
| 42 | Brentwood Town Centre | |
| 43 | Holdom | |
| 44 | Sperling–Burnaby Lake | |
| 45 | Lake City Way | |
| ↩ 19 | Production Way–University | shared with Expo |
| ↩ 18 | Lougheed Town Centre | shared with Expo |
| 46 | Burquitlam | |
| 47 | Moody Centre | |
| 48 | Inlet Centre | |
| 49 | Coquitlam Central | |
| 50 | Lincoln | |
| 51 | Lafarge Lake–Douglas | Eastern terminus |

## Canada Line (LED 52–66, + 2 shared/↩)

| LED | Station | Notes |
|-----|---|---|
| ↩ 0 | Waterfront | shared with Expo |
| 52 | Vancouver City Centre | |
| 53 | Yaletown–Roundhouse | |
| 54 | Olympic Village | |
| ↩ 35 | Broadway–City Hall | shared with Millennium (post-extension) |
| 55 | King Edward | |
| 56 | Oakridge–41st Avenue | |
| 57 | Langara–49th Avenue | |
| 58 | Marine Drive | |
| 59 | Bridgeport | Branch point |
| 60 | Templeton | Airport branch |
| 61 | Sea Island Centre | |
| 62 | YVR–Airport | |
| 63 | Capstan | **New (opened Dec 2024)** — Richmond branch |
| 64 | Aberdeen | |
| 65 | Lansdowne | |
| 66 | Richmond–Brighouse | |

## Extras

| LED | Marker | Notes |
|-----|---|---|
| 67 | SeaBus (Burrard Inlet crossing) | v1 had this (index 126); optionally animate as a slow ferry blink between Waterfront and Lonsdale Quay |

## Notes for implementation

- **Verify names against TransLink before silkscreen** — the Surrey–Langley working names
  (Green Timbers, 152 St, Fleetwood, Bakerview–166 St, Hillcrest–184 St, Clayton,
  Willowbrook, Langley City Centre) could still change before opening.
- v1 firmware already contains the Broadway Extension stations in its Millennium tables,
  so its animation logic needs no new concepts — only renumbering to the single-LED-per-
  station indices above.
- Physical chain routing may prefer a different order than the logical one — that's fine.
  Keep the *logical* table in one CSV/JSON file and generate both the firmware header and a
  cross-check against the KiCad reference designators from it.

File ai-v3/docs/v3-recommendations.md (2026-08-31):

# V3 Recommendations

Target: a smaller **square** board, iconic map, one WS2812B per station (all new stations
included), no controller populated — a **XIAO footprint on the back** instead.

## 1. Treat v3 as "v2 finished on a square outline"

v2 already has the right architecture (68 LEDs, XIAO-on-back, iconic map). Recommended
starting move:

1. Create `ai-v3/hardware/` by copying the v2 KiCad project, and `ai-v3/input/` by moving
   `v2/input/map3.svg` there (commit it first — it currently has uncommitted changes).
2. Keep the v2 local libraries as-is: `C5349954-led` (XL-1615RGBC-WS2812B-1),
   `Seeed Studio XIAO`, `C318884-button`.

## 2. Board size — decide first, everything else follows

`map3.svg` is drawn at 150 × 150 mm; v2's board was 100 × 82.9 mm. Options:

| Size | Pros | Cons |
|---|---|---|
| **100 × 100 mm (recommended)** | JLCPCB/PCBWay cheap-prototype sweet spot; noticeably smaller than v1; iconic map with 68 stations fits comfortably | Station-name silkscreen gets small (~1 mm text) — still readable but near the limit |
| 150 × 150 mm | map3.svg needs no rescaling; roomy labels | Not really "smaller"; higher fab cost |
| 70–80 mm square | Very cute, coaster-sized | 68 × 1615 LEDs + names get very tight; Expo/Millennium shared corridor gets congested; probably drop station names |

Recommendation: **100 × 100 mm**, scale map3.svg down 2/3 in Inkscape (svg2shenzhen carries
mm through faithfully). Verify minimum silkscreen text height (JLC: ≥ 1 mm height,
≥ 0.15 mm stroke) after scaling; if names don't fit, keep names for interchanges/termini
only and put the full legend on the back silkscreen.

## 3. XIAO footprint on the back

- Use the **XIAO-*-SMD variant** (castellated pads, module lies flat) on `B.Cu`, as v2
  already does. Also add the two **B.Cu keep-out / courtyard** considerations:
  - Nothing on the front side directly opposite the module if you ever want the DIP
    (through-hole header) variant as a fallback — consider placing both footprints
    overlapped (SMD pads + DIP holes), a common trick that supports either mounting.
- **Pin budget is tiny and that's fine**: 5 V, GND, one data pin, plus 2–4 GPIOs for
  buttons. All XIAO family members pin out 5V/GND/3V3 identically, so the board stays
  controller-agnostic (RP2040, ESP32-C3 for WiFi clock/real-time data, nRF52840…).
- Orient the module so the **USB-C connector faces (and slightly overhangs or sits at) the
  board edge** — this is the power inlet and programming port. The XIAO's reset/boot
  buttons face away from the board when surface-mounted, so they stay accessible, but add
  labelled test points or two small pads for RESET/BOOT anyway.
- If the board will hang on a wall, USB-C at the **bottom edge** hides the cable best.

## 4. Electrical design (close the two v2 gaps)

- **Level shifting.** The XIAO drives data at 3.3 V; WS2812B at 5 V wants VIH ≥ 0.7 × VDD
  = 3.5 V. It often works anyway, but don't ship marginal: reuse v1's proven
  **74AHC1G125** (SOT-23-5, C23654) powered at 5 V as a data buffer. It costs pennies and
  removes the #1 flicker risk.
- **Decoupling.** 7 caps for 68 LEDs (v2) is too thin. The XL-1615 is small; a pragmatic
  middle ground is **one 100 nF–1 µF 0402 per 2–4 LEDs** distributed along the chain, plus
  **2 × 22 µF bulk** near the XIAO 5 V feed. (v1 used one 1 µF per LED — fine too, but
  doubles placement count.)
- **Power budget.** 68 LEDs × 60 mA worst case ≈ 4 A — far beyond USB. Not a hardware
  problem if firmware caps it: keep v1's brightness limit and add FastLED's
  `setMaxPowerInVoltsAndMilliamps(5, 1500)`. At demo brightness (32/255) the whole board
  draws well under 500 mA. Make 5 V and GND pours wide (front pour + back pour) since the
  chain snakes the whole board.
- **Series resistor** (~300 Ω) on the data line at the buffer output, and keep v1's
  bug-shaped test points if there's room — they were a signature detail.

## 5. LED chain and station data

- **One authoritative station list** drives everything — see
  [station-list.md](station-list.md): 67 stations + SeaBus = **68 LEDs**, matching the 68
  markers already in map3.svg/v2.
- Chain order recommendation: route the data chain **line by line** (Expo including both
  branches → Millennium → Canada Line including both branches → SeaBus) so firmware line
  tables are contiguous ranges instead of scattered indices. Interchange stations get **one
  LED, owned by one line**, and the other line's table simply references that index (v1's
  firmware already works this way for Production Way/Lougheed).
- Mark future stations (Broadway Extension opens ~2027, Surrey–Langley ~2029, already
  under construction) with a distinct silkscreen ring so the map is honest today and
  correct later. Firmware can skip/dim them in "current network" mode.

## 6. Artwork / fab finish

- Keep the svg2shenzhen pipeline from v1/v2 (`Edge.Cuts`, `F.Cu`, `F.Mask`, `F.SilkS`,
  `B.SilkS` layers in map3.svg are already set up for it).
- Silkscreen is single-colour, so line identity must come from geometry: the classic trick
  (used in v1) is drawing the route lines as **exposed copper (F.Cu + F.Mask openings)** so
  they render as gold/silver traces, with silkscreen for names and water/background. With
  ENIG + black soldermask this looks excellent. Optional: order variants with different
  soldermask colours per batch.
- Put the credits, LED index legend, and firmware URL/QR code on the back silkscreen around
  the XIAO.

## 7. Firmware

- Copy `v1/firmware` to `ai-v3/firmware`, change `platformio.ini` to
  `board = seeed_xiao_rp2040` (it already targets the `raspberrypi` platform, so this is a
  one-line change), set `NUM_LEDS = 68`, and regenerate the index tables from the station
  list. The two-directional-LEDs concept collapses to one index per station; keep the
  multi-train animation by fading a train through the single per-station LED.
- Wire the 2–4 buttons (v2 already placed 4) to mode/brightness/speed/next-line, active-low
  with internal pull-ups — no external resistors needed.
- Generate the station table from `station-list.md` (or a CSV) with a small script rather
  than hand-numbering 68 entries again.

## 8. Process / repo hygiene

1. **Commit `v2/input/map3.svg` now** (its 460-line local change is the newest map work).
2. Structure `ai-v3/` as `hardware/`, `firmware/`, `input/`, `docs/` (matching v1).
3. Before ordering: run DRC, generate JLC BOM/CPL like v1's `production/` folder, and
   sanity-check the LED chain order visually (KiCad 8 can highlight the DIN/DOUT net path).
4. Order a **5-board prototype**; hand-solder one XIAO to validate before committing to a
   panel run.

## Open questions (decide before layout)

1. **Board size** — 100 × 100 mm recommended; confirm.
2. **Station names on front?** At 100 mm they're marginal; interchanges-only is the safe call.
3. **Include SeaBus LED** (v1 had it; the 68th marker suggests v2 kept it) — keep?
4. **Buttons: how many and which face?** Back-side buttons keep the front clean but are
   awkward wall-mounted; edge-adjacent front buttons are friendlier.
5. **Mounting**: M3 holes in corners, or a single keyhole slot on the back for wall hanging?
6. **Which XIAO ships as the "reference" module** — RP2040 (cheapest, matches existing
   firmware) or ESP32-C3 (enables live TransLink data / clock modes later)? The footprint
   supports both; the choice only affects documentation and default firmware.

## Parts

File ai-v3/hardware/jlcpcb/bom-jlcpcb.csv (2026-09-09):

Comment | Designator | Footprint | LCSC Part #
XL-1615RGBC-WS2812B | LED1,LED2,LED3,LED4,LED5,LED6,LED7,LED8,LED9,LED10,LED11,LED12,LED13,LED14,LED15,LED16,LED17,LED18,LED19,LED20,LED21,LED22,LED23,LED24,LED25,LED26,LED27,LED28,LED29,LED30,LED31,LED32,LED33,LED34,LED35,LED36,LED37,LED38,LED39,LED40,LED41,LED42,LED43,LED44,LED45,LED46,LED47,LED48,LED49,LED50,LED51,LED52,LED53,LED54,LED55,LED56,LED57,LED58,LED59,LED60,LED61,LED62,LED63,LED64,LED65,LED66,LED67,LED68 | LED-SMD_4P-L1.6-W1.5_XL-1615RGBC-WS2812B-1 | C5349954
10uF,10V,X5R | ROW0,ROW1,ROW2,ROW3,ROW4,ROW5,ROW6,ROW7 | C_0402_1005Metric | C52923

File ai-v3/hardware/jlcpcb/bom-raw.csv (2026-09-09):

Reference | Value | Footprint | LCSC Part | LCSC | DNP
+5V1,+5V2,GND1,LED_IN1,LED_OUT1 | TestPoint | TestPoint:TestPoint_Pad_3.0x3.0mm
LED1-LED68 | XL-1615RGBC-WS2812B | C5349954-led:LED-SMD_4P-L1.6-W1.5_XL-1615RGBC-WS2812B-1 | C5349954
ROW0-ROW7 | 10uF,10V,X5R | Capacitor_SMD:C_0402_1005Metric |  | C52923
U1 | XIAO-RP2040-DIP | Seeed Studio XIAO:XIAO-RP2040-SMD

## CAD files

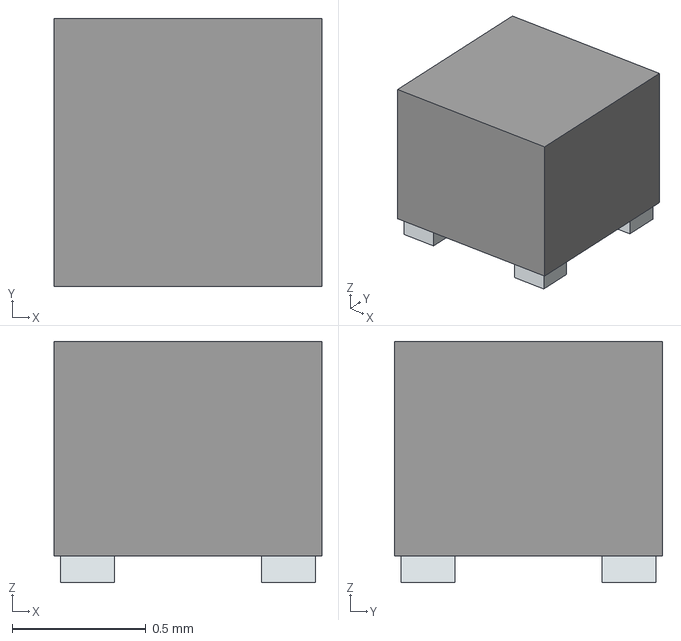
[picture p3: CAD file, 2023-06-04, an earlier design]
v1/hardware/vancouver-skytrain-pcb/XL-1010RGBC-WS2812B.stp
1.00 x 1.00 x 0.9 mm
Pins

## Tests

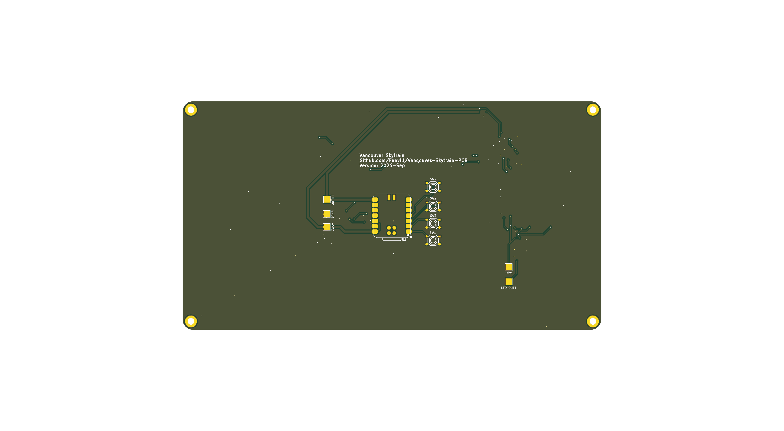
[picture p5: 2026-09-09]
ai-v3/test-results/board-bottom-transparent.png

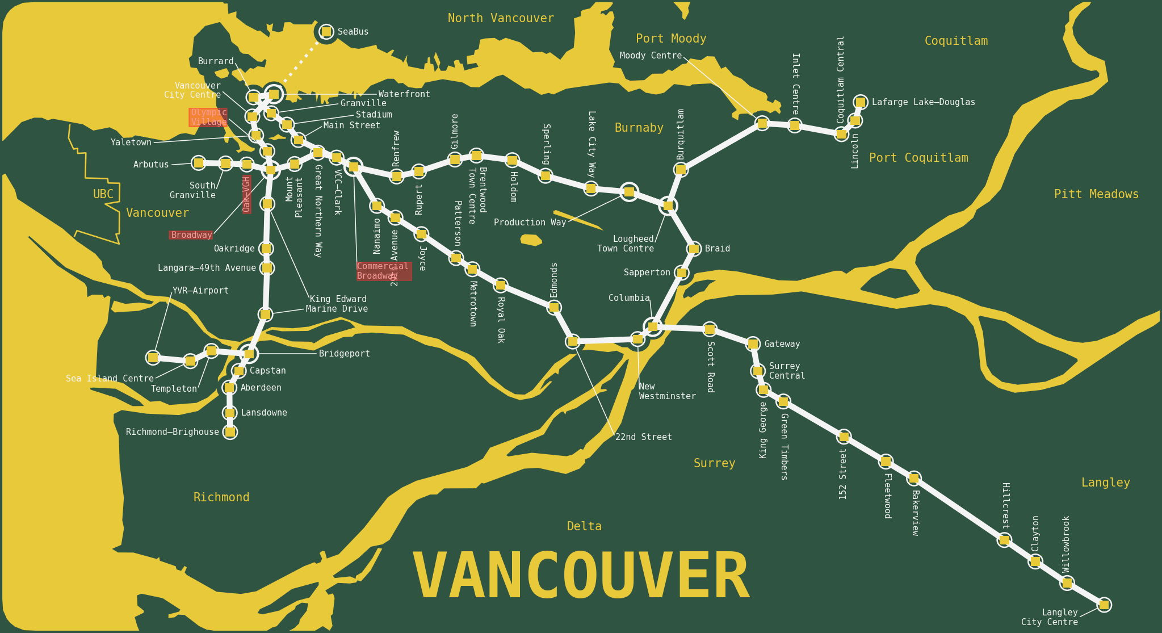
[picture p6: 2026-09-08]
ai-v3/test-results/preview.png

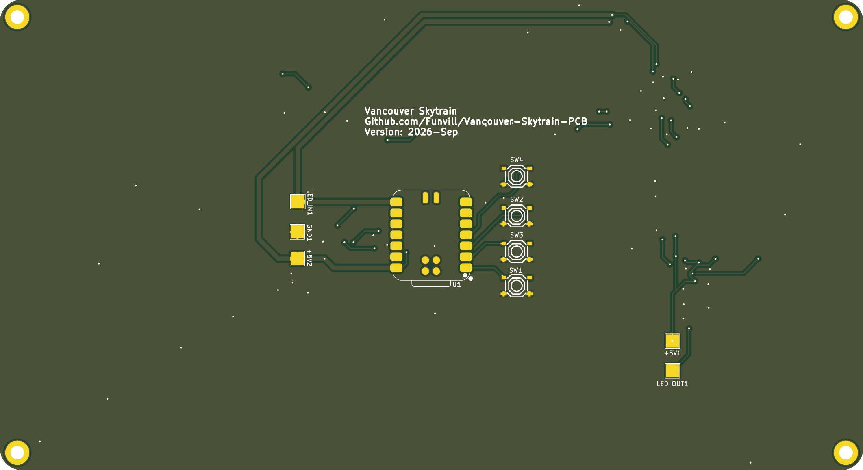
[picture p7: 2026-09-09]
ai-v3/test-results/board-bottom-mask.png

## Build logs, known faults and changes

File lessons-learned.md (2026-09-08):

# Lessons learned — building a transit-map LED PCB

Collected while building v3 of the Vancouver SkyTrain board. Written for
the next board of this kind (another city, another network), so each
lesson says what to do, not just what went wrong.

## 1. Get the landmass right first, on its own, before anything touches the PCB

The single biggest time sink of this project was geography. Five
successive sources were tried before the shape was right:

| Attempt | Source | Why it failed |
|---|---|---|
| 1 | Hand-authored polygons "resembling" Vancouver | Invented coastline; every review found something wrong |
| 2 | TransLink's schematic network map (PDF, vector-traced) | A schematic is not a map: its page is 1.26:1 where the region is 2:1, so everything south of Broadway was stretched and the Fraser became a 45° band; it also draws no coastline where it doesn't need one, so "the left edge should end in water" had no data behind it |
| 3 | The v1 project's hand-drawn "natural" map | Better shape, but a hand drawing: squeezed north–south, station layout not geographic, and it had to be registered to the board by fitting dots in a PNG |
| 4 | OpenStreetMap coastline via Overpass | Correct where it exists — but in this region OSM's `natural=coastline` stops at Burrard Inlet; the Fraser's arms are `natural=water` riverbank polygons that were never loaded, so Sea Island, Lulu Island and the whole estuary collapsed into land |
| 5 | **BC Freshwater Atlas (provincial 1:20k hydrography, WFS)** | Worked first time |

What made #5 work is worth generalising:

- **Prefer sources that give polygons, not lines.** Assembling coastline
  *lines* into land/sea faces (polygonize + orientation votes) is where
  the OSM attempt went wrong. The FWA gives land (watershed groups end at
  the coast → sea = frame − land), rivers and lakes all as polygons; there
  was nothing to assemble.
- **Prefer the national / provincial mapping agency over crowd-sourced
  data for water.** Look for a WFS with a bbox parameter (BC:
  `openmaps.gov.bc.ca/geo/pub/wfs`; most provinces/states/countries have
  an equivalent). Cache the raw responses in the repo so the build runs
  offline and is reproducible.
- **Make a standalone geography render** (`geo_fwa.py`) and get it
  approved before wiring it into the board pipeline. Iterating on the
  shape through KiCad renders costs minutes per round; matplotlib costs
  seconds.
- **Simplify deliberately, not by accident.** A morphological open/close
  (`buffer(-d).buffer(2d).buffer(-d)`) plus `simplify()` removes nooks;
  filling river islands below a size threshold and dropping bay tips that
  are mostly outside the frame keeps the picture clean. Keep lakes by a
  *name whitelist* — an area threshold lets 10 ha ponds in.
- **Check the obvious landmarks by eye**: the airport island, the river
  reaching the sea, the big lakes. Every one of those was missing at some
  point and no checker caught it; a human did.

## 2. Use real station positions, then bend them only where physics demands

Station positions came, in order, from a schematic, a hand drawing and
finally OSM nodes (`railway=station` + `station=subway`). Real positions
put stations on the correct side of rivers automatically — "Surrey
Central is in the water" is a symptom of a bad source, not something to
patch.

The only justified distortion is the LED pitch: downtown stations are
~500 m apart, which is 1.6 mm at 3.1 mm/km. Spread them along their own
line direction, then run a global pairwise separation, and record the
floor as a constant with the reason next to it. **The floor is 3.3 mm,
not the 2.5 mm the package suggests**: LED footprints rotate to aim DOUT
at the next LED, and two diagonal neighbours' pads overlap at 2.8 mm.
Found by DRC after the layout looked fine.

## 3. Size the board to the map's aspect, not the other way round

A square board for a 2:1 region wastes half the area and pushes the map
scale down until labels stop fitting. Decide the frame (lat/lon box)
first, derive the board size from it at the largest width the fab and
budget allow, and treat "leave a blank band" as a warning sign. Going
from 150 mm square to 200 × 109 mm raised the scale 40 % and solved more
label problems than any algorithm did.

## 4. Labels: the tight cluster decides everything — plan for it

Downtown (six stations inside 1 km, three lines crossing) is where every
labelling scheme broke. What eventually held:

- One shared text height (1.1 mm, 0.14 mm stroke — a 1:8 ratio keeps the
  stroke font's counters open), a fixed standoff from the LED, two-line
  wrapping at the name's en-dash instead of abbreviations, a "beside the
  line" candidate so labels can run along a corridor, and leader lines
  as a last resort.
- A checker that models everything on the board — other labels with a
  breathing gap, pads (own and others'), routes including the label's
  own segment beyond the standoff, leaders vs everything, silk furniture,
  copper text — because every unmodelled thing became a real overlap.
- **Greedy placement does not converge in a cluster**; a repair loop
  cycled forever. Simulated annealing over all labels found joint layouts
  the greedy pass couldn't, and even that left a handful for a human.
  Budget for a hand pass and make it round-trip safe (next lesson).
- Some things are not label problems: "Vancouver City Centre" and
  "Granville" are 300 m apart; no layout algorithm fixes that, a bigger
  board does.

## 5. Make hand edits survive regeneration — deterministic ids + an importer

The generated board is edited by hand in KiCad; the generator regenerates
it. Without a round trip, one of them always loses. What worked:

- Every generated item gets a **deterministic uuid** (`uuid5(namespace,
  key)`, keys like `label:waterfront`), and the exporter keeps a manifest
  of uuid → key so it can remove exactly what it wrote last time
  (idempotent regeneration, verified by running it twice and checking for
  duplicate uuids).
- An **importer** finds each item on the board by uuid and writes the
  human's changes back into the data (position, rotation, justification,
  text, deleted leaders). Things the human *deleted* are recorded as a
  `suppressed_art` list the exporter honours.
- Prove it with an import → export comparison on the real board: 0 of 99
  text items differing is the bar.

And the mistake that made this urgent: the user had started editing in
KiCad while the generator was still being run. `git add` swept their
edits into a commit, a regeneration overwrote them on disk, and a
"refresh the backup" step overwrote the backup too. Git had the edits.
**Take the backup before the first regeneration, never overwrite a backup,
and tag the commit.**

## 6. Model the fab's reality, not the editor's

- KiCad's stroke `type dash` line style is an **editor display hint**; it
  does not survive to gerbers, SVG export or 3D render. Draw dashes as
  real short segments.
- Text angles outside [−90°, 90°] render upside-down; rotation is rigid.
- KiCad's bold stroke font is ~10 % wider than a 0.85 × size-per-character
  estimate; the wordmark walked into a river because of it. Measure once
  from a render and put the factor in the code.
- Bare-copper "water" needs an F.Cu polygon **and** the same polygon on
  F.Mask; keep it 0.4 mm from the edge (and inside the corner radius) and
  ≥ 2 mm from every pad — carve clearance disks in the data, and repel
  edges again at export time. A real coastline puts stations *inside*
  water (ferry terminals, river banks); nudge those onto land.
- `silk_over_copper`, `silk_overlap` and `solder_mask_bridge` DRC warnings
  are the price of this aesthetic; `clearance`, `copper_edge_clearance`
  and `shorting_items` are not negotiable. Say which is which in the
  README so the next person doesn't panic (or ignore the wrong one).
- A newer KiCad silently upgrades the file format on save; an older
  `kicad-cli` then fails with "Failed to load board". Pin the CLI to the
  newest install.

## 7. Process lessons

- **Verify against the source, not against the previous fix.** Two rounds
  were spent adding a "missing" peninsula that the source map never
  showed. Re-read the source before patching a mismatch.
- **Sub-agent design critiques were worth it**: an independent
  composition / cartography / labelling review produced the list that
  drove the whole redesign (water to the edge, thin uniform routes,
  station rings, wordmark on land, drop the legend).
- **Keep every generated intermediate in the repo** (cached WFS/Overpass
  responses, station tables, preview PNGs). Builds stay reproducible and
  reviewers can see what changed.
- **Write the "what's wrong with this picture" checklist down**: river
  reaches the sea, airport island present, big lakes present, all
  stations on land, no label on bare copper, wordmark on land, nothing
  in the corner radius. Run it by eye on every render.
- **Automate the screenshot.** `kicad-cli pcb render` (and the matplotlib
  preview) after every change meant problems were seen the same minute
  they were made.

## 8. Reusing this for another city

The pipeline is city-agnostic below `vancouver.json`. For a new city you
need: (a) a lat/lon frame and board width in `geo_fwa.py`'s successor,
(b) polygon hydrography for the region (agency WFS first, OSM
`natural=water` second), (c) station lat/lon (OSM nodes, checked by eye),
(d) the line definitions and LED chain order, (e) a pitch floor for the
LED package and footprint rotation you use. Then: geography preview →
approve → data build → `auto_label` → `preview_map` → hand pass in KiCad
→ `import_labels` → verification list → render.

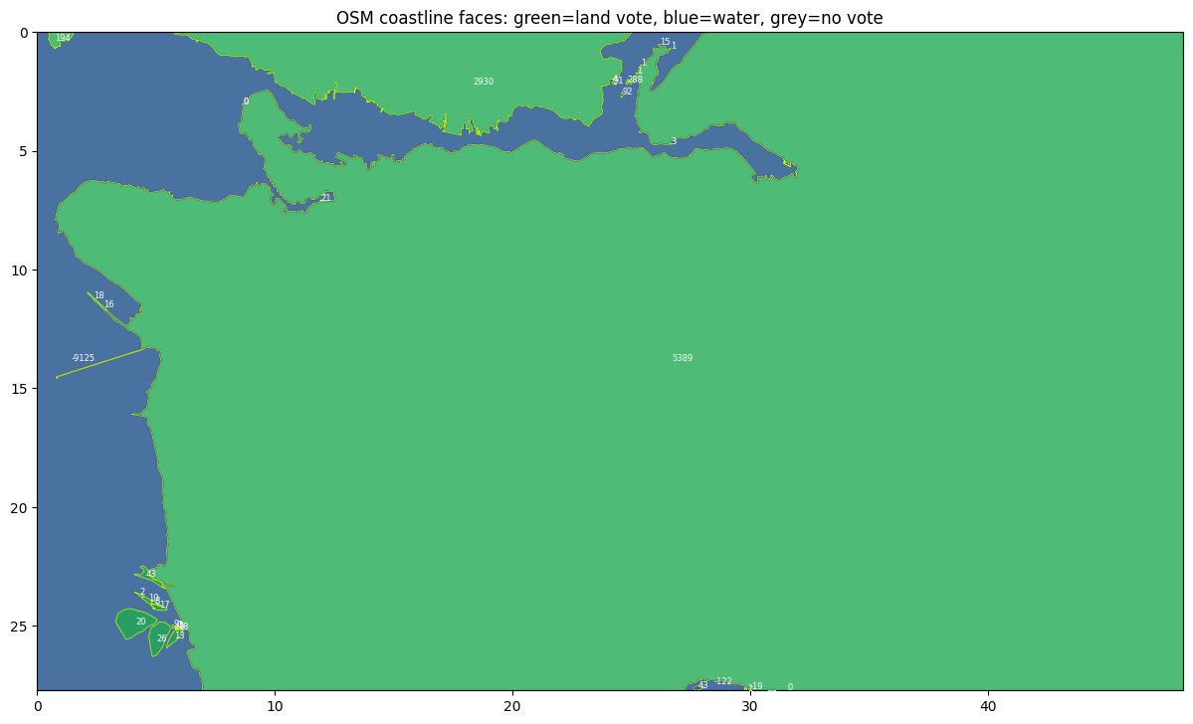
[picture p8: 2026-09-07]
ai-v3/test-results/geo-debug-faces.png

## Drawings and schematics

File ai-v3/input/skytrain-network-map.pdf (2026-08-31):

# SkyTrain Network

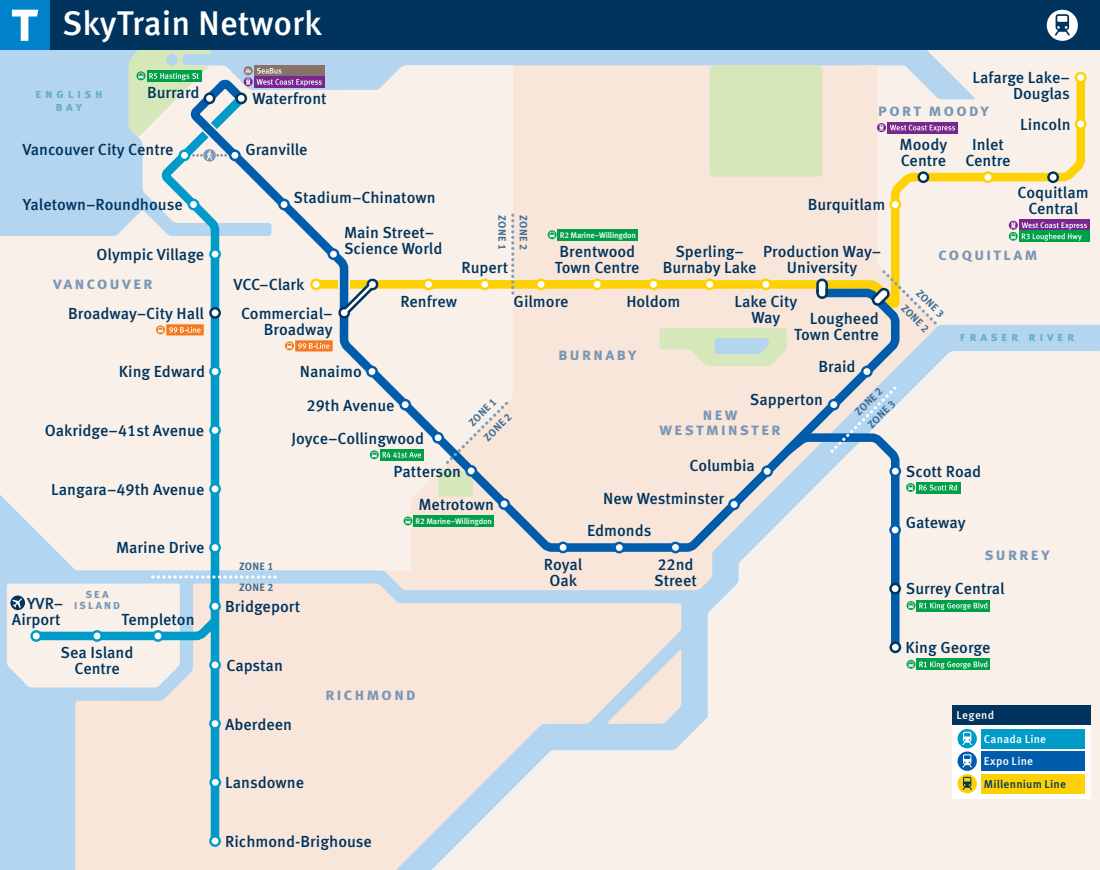
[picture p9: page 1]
fraser river; english bay; R2 Marine–Willingdon; Capstan; Bridgeport; Aberdeen; Lansdowne; Richmond-Brighouse; Burrard; Yaletown–Roundhouse; Oakridge–41st Avenue; Langara–49th Avenue; Marine Drive; King Edward; Scott Road; Gateway; Surrey Central; King George; 22nd Street; Edmonds; 29th Avenue; Joyce–Collingwood; Patterson; Metrotown; Royal Oak; Nanaimo; Lougheed Town Centre; Lake City Way; Coquitlam Central; Lafarge Lake– Douglas; Lincoln; Gilmore; Holdom; Templeton; Sea Island Centre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

Vancouver City Centre

Olympic Village
vancouver
Broadway–City Hall

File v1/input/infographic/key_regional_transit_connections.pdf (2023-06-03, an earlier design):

## Lonsdale Quay

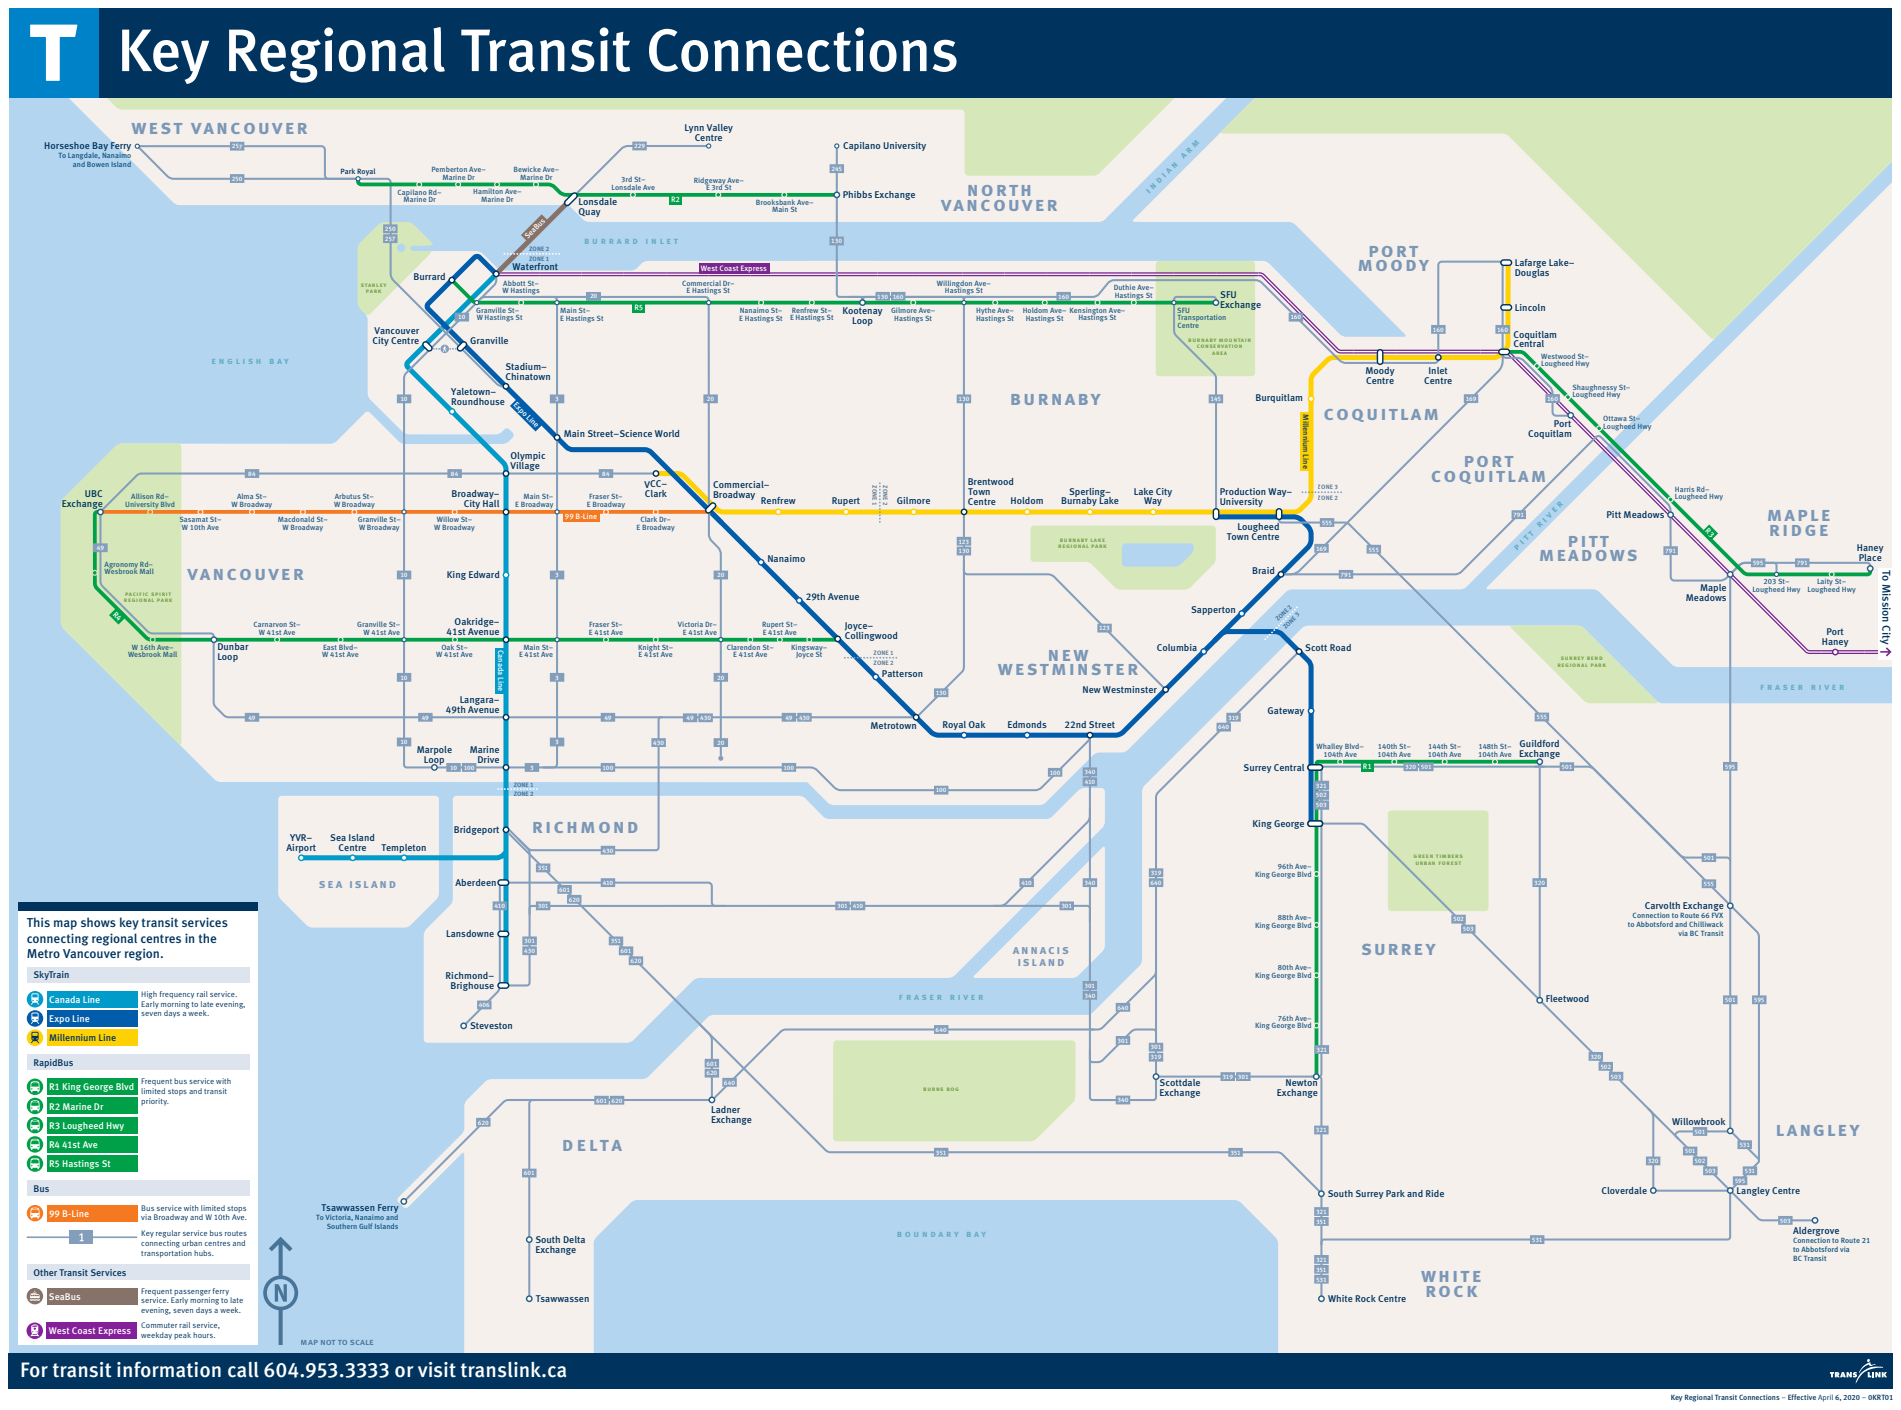
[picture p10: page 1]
Park Royal; Capilano Rd– Marine Dr; Hamilton Ave– Marine Dr; 3rd St– Lonsdale Ave; Ridgeway Ave– E 3rd St; Brooksbank Ave– Main St; Pemberton Ave– Marine Dr; Bewicke Ave– Marine Dr; Guildford Exchange; UBC Exchange; Waterfront; Burrard; Pitt Meadows; Maple Meadows; Cloverdale; Langley Centre; Willowbrook; Scott Road; Gateway; King George; Surrey Central; Abbott St– W Hastings; Granville St– W Hastings St; Main St– E Hastings St; Main St– E Broadway; Fraser St– E Broadway; Clark Dr– E Broadway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

Key Regional Transit Connections

Horseshoe Bay Ferry
To Langdale, Nanaimo
and Bowen Island

West Coast Express
Commercial Dr–
E Hastings St

Hastings St Kootenay
Loop

Broadway– City Hall

To Mission City

W 16th Ave– Wesbrook Mall

96th Ave–
King George Blvd

Carvolth Exchange
Connection to Route 66 FVX
to Abbotsford and Chilliwack

88th Ave–

This map shows key transit services
connecting regional centres in the
Metro Vancouver region.

via BC Transit

80th Ave–

High frequency rail service.
Early morning to late evening,
seven days a week.

76th Ave–

Frequent bus service with
limited stops and transit
priority.

R1 King George Blvd
R2 Marine Dr
R3 Lougheed Hwy
R4 41st Ave
R5 Hastings St

South Surrey Park and Ride

Tsawwassen Ferry
To Victoria, Nanaimo and
Southern Gulf Islands

via Broadway and W 10th Ave.
Key regular service bus routes
connecting urban centres and
strait
transportation hubs.

Aldergrove
Connection to Route 21
to Abbotsford via
BC Transit

Other Transit Services

Frequent passenger ferry
service. Early morning to late
evening, seven days a week.
Commuter rail service,
weekday peak hours.

For transit information call 604.953.3333 or visit translink.ca

map not to scale

Key Regional Transit Connections – Effective April 6, 2020 – 0KRT01

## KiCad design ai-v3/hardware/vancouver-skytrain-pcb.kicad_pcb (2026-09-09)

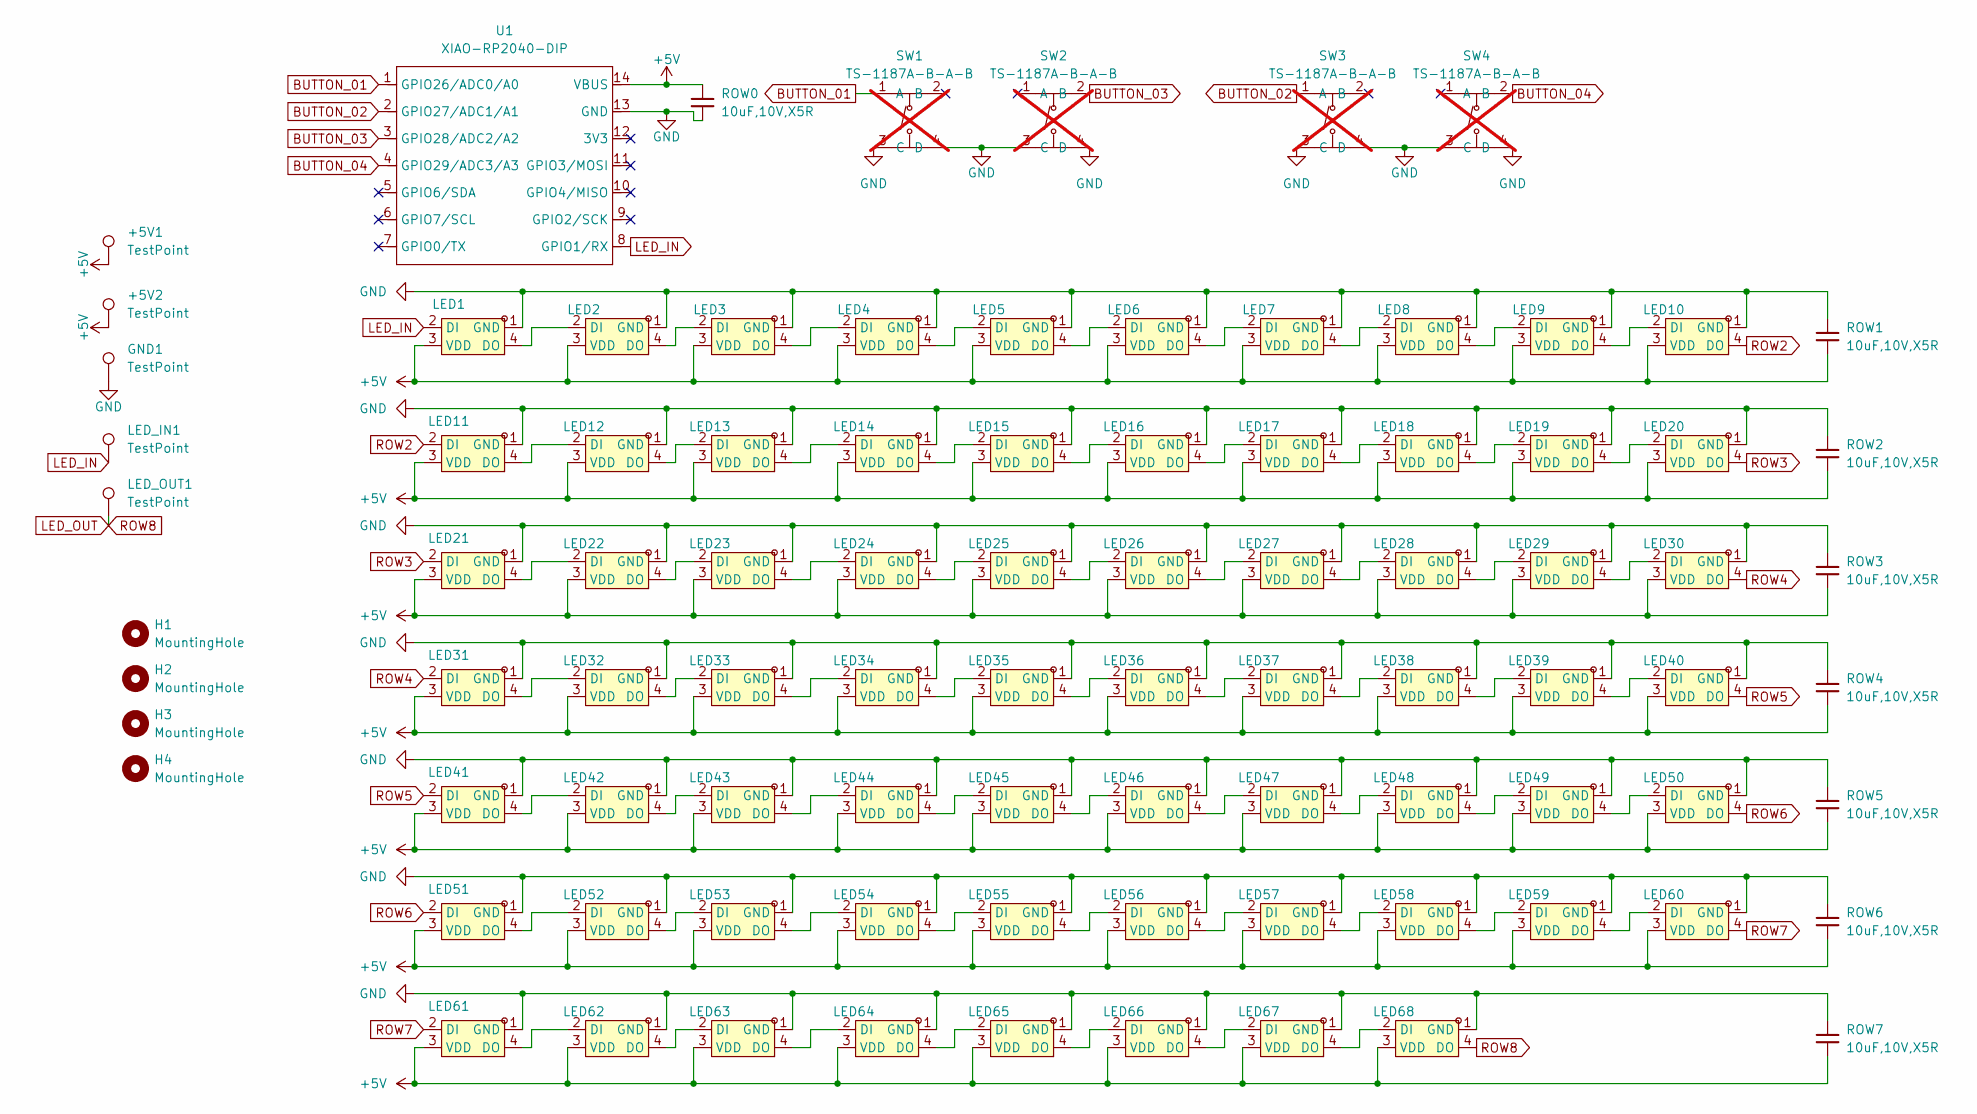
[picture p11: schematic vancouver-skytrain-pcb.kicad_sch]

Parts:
+5V1, +5V2: TestPoint; TestPoint_Pad_3.0x3.0mm
GND1: TestPoint; TestPoint_Pad_3.0x3.0mm
H1, H2, H3, H4: MountingHole; MountingHole_3.2mm_M3_DIN965_Pad_TopBottom
LED1, LED2, LED3, LED4, LED5, LED6, LED7, LED8, LED9, LED10, LED11, LED12, LED13, LED14, LED15, LED16, LED17, LED18, LED19, LED20, LED21, LED22, LED23, LED24, LED25, LED26, LED27, LED28, LED29, LED30, LED31, LED32, LED33, LED34, LED35, LED36, LED37, LED38, LED39, LED40, LED41, LED42, LED43, LED44, LED45, LED46, LED47, LED48, LED49, LED50, LED51, LED52, LED53, LED54, LED55, LED56, LED57, LED58, LED59, LED60, LED61, LED62, LED63, LED64, LED65, LED66, LED67, LED68: XL-1615RGBC-WS2812B; LED-SMD_4P-L1.6-W1.5_XL-1615RGBC-WS2812B-1; LCSC Part C5349954
LED_IN1: TestPoint; TestPoint_Pad_3.0x3.0mm
LED_OUT1: TestPoint; TestPoint_Pad_3.0x3.0mm
ROW0, ROW1, ROW2, ROW3, ROW4, ROW5, ROW6, ROW7: 10uF,10V,X5R; C_0402_1005Metric; MFGPN CL05A105KA5NQNC; LCSC C52923
SW1, SW2, SW3, SW4: TS-1187A-B-A-B; SW-SMD_4P-L5.1-W5.1-P3.70-LS6.5-TL_H1.5; LCSC Part C318884; not fitted
U1: XIAO-RP2040-DIP; XIAO-RP2040-SMD

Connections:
+5V: +5V1.1 (1_1), +5V2.1 (1_1), LED1.3 (VDD), LED2.3 (VDD), LED3.3 (VDD), LED4.3 (VDD), LED5.3 (VDD), LED6.3 (VDD), LED7.3 (VDD), LED8.3 (VDD), LED9.3 (VDD), LED10.3 (VDD), LED11.3 (VDD), LED12.3 (VDD), LED13.3 (VDD), LED14.3 (VDD), LED15.3 (VDD), LED16.3 (VDD), LED17.3 (VDD), LED18.3 (VDD), LED19.3 (VDD), LED20.3 (VDD), LED21.3 (VDD), LED22.3 (VDD), LED23.3 (VDD), LED24.3 (VDD), LED25.3 (VDD), LED26.3 (VDD), LED27.3 (VDD), LED28.3 (VDD), LED29.3 (VDD), LED30.3 (VDD), LED31.3 (VDD), LED32.3 (VDD), LED33.3 (VDD), LED34.3 (VDD), LED35.3 (VDD), LED36.3 (VDD), LED37.3 (VDD), LED38.3 (VDD), LED39.3 (VDD), LED40.3 (VDD), LED41.3 (VDD), LED42.3 (VDD), LED43.3 (VDD), LED44.3 (VDD), LED45.3 (VDD), LED46.3 (VDD), LED47.3 (VDD), LED48.3 (VDD), LED49.3 (VDD), LED50.3 (VDD), LED51.3 (VDD), LED52.3 (VDD), LED53.3 (VDD), LED54.3 (VDD), LED55.3 (VDD), LED56.3 (VDD), LED57.3 (VDD), LED58.3 (VDD), LED59.3 (VDD), LED60.3 (VDD), LED61.3 (VDD), LED62.3 (VDD), LED63.3 (VDD), LED64.3 (VDD), LED65.3 (VDD), LED66.3 (VDD), LED67.3 (VDD), LED68.3 (VDD), ROW0.1, ROW1.2, ROW2.2, ROW3.2, ROW4.2, ROW5.2, ROW6.2, ROW7.2, U1.14 (VBUS)
BUTTON_01: SW1.1 (A), U1.1 (GPIO26/ADC0/A0)
BUTTON_02: SW2.1 (A), SW3.1 (A), U1.2 (GPIO27/ADC1/A1)
BUTTON_03: SW2.2 (B), SW3.2 (B), U1.3 (GPIO28/ADC2/A2)
BUTTON_04: SW4.2 (B), U1.4 (GPIO29/ADC3/A3)
GND: GND1.1 (1_1), LED1.1 (GND), LED2.1 (GND), LED3.1 (GND), LED4.1 (GND), LED5.1 (GND), LED6.1 (GND), LED7.1 (GND), LED8.1 (GND), LED9.1 (GND), LED10.1 (GND), LED11.1 (GND), LED12.1 (GND), LED13.1 (GND), LED14.1 (GND), LED15.1 (GND), LED16.1 (GND), LED17.1 (GND), LED18.1 (GND), LED19.1 (GND), LED20.1 (GND), LED21.1 (GND), LED22.1 (GND), LED23.1 (GND), LED24.1 (GND), LED25.1 (GND), LED26.1 (GND), LED27.1 (GND), LED28.1 (GND), LED29.1 (GND), LED30.1 (GND), LED31.1 (GND), LED32.1 (GND), LED33.1 (GND), LED34.1 (GND), LED35.1 (GND), LED36.1 (GND), LED37.1 (GND), LED38.1 (GND), LED39.1 (GND), LED40.1 (GND), LED41.1 (GND), LED42.1 (GND), LED43.1 (GND), LED44.1 (GND), LED45.1 (GND), LED46.1 (GND), LED47.1 (GND), LED48.1 (GND), LED49.1 (GND), LED50.1 (GND), LED51.1 (GND), LED52.1 (GND), LED53.1 (GND), LED54.1 (GND), LED55.1 (GND), LED56.1 (GND), LED57.1 (GND), LED58.1 (GND), LED59.1 (GND), LED60.1 (GND), LED61.1 (GND), LED62.1 (GND), LED63.1 (GND), LED64.1 (GND), LED65.1 (GND), LED66.1 (GND), LED67.1 (GND), LED68.1 (GND), ROW0.2, ROW1.1, ROW2.1, ROW3.1, ROW4.1, ROW5.1, ROW6.1, ROW7.1, SW1.3 (C), SW1.4 (D), SW2.3 (C), SW2.4 (D), SW3.3 (C), SW3.4 (D), SW4.3 (C), SW4.4 (D), U1.13 (GND)
LED_IN: LED1.2 (DI), LED_IN1.1 (1_1), U1.8 (GPIO1/RX)
LED_OUT: LED68.4 (DO), LED_OUT1.1 (1_1)
unnamed: LED1.4 (DO), LED2.2 (DI)
unnamed: LED2.4 (DO), LED3.2 (DI)
unnamed: LED3.4 (DO), LED4.2 (DI)
unnamed: LED4.4 (DO), LED5.2 (DI)
unnamed: LED5.4 (DO), LED6.2 (DI)
unnamed: LED6.4 (DO), LED7.2 (DI)
unnamed: LED7.4 (DO), LED8.2 (DI)
unnamed: LED8.4 (DO), LED9.2 (DI)
unnamed: LED9.4 (DO), LED10.2 (DI)
unnamed: LED11.4 (DO), LED12.2 (DI)
unnamed: LED12.4 (DO), LED13.2 (DI)
unnamed: LED13.4 (DO), LED14.2 (DI)
unnamed: LED14.4 (DO), LED15.2 (DI)
unnamed: LED15.4 (DO), LED16.2 (DI)
unnamed: LED16.4 (DO), LED17.2 (DI)
unnamed: LED17.4 (DO), LED18.2 (DI)
unnamed: LED18.4 (DO), LED19.2 (DI)
unnamed: LED19.4 (DO), LED20.2 (DI)
unnamed: LED21.4 (DO), LED22.2 (DI)
unnamed: LED22.4 (DO), LED23.2 (DI)
unnamed: LED23.4 (DO), LED24.2 (DI)
unnamed: LED24.4 (DO), LED25.2 (DI)
unnamed: LED25.4 (DO), LED26.2 (DI)
unnamed: LED26.4 (DO), LED27.2 (DI)
unnamed: LED27.4 (DO), LED28.2 (DI)
unnamed: LED28.4 (DO), LED29.2 (DI)
unnamed: LED29.4 (DO), LED30.2 (DI)
unnamed: LED31.4 (DO), LED32.2 (DI)
unnamed: LED32.4 (DO), LED33.2 (DI)
unnamed: LED33.4 (DO), LED34.2 (DI)
unnamed: LED34.4 (DO), LED35.2 (DI)
unnamed: LED35.4 (DO), LED36.2 (DI)
unnamed: LED36.4 (DO), LED37.2 (DI)
unnamed: LED37.4 (DO), LED38.2 (DI)
unnamed: LED38.4 (DO), LED39.2 (DI)
unnamed: LED39.4 (DO), LED40.2 (DI)
unnamed: LED41.4 (DO), LED42.2 (DI)
unnamed: LED42.4 (DO), LED43.2 (DI)
unnamed: LED43.4 (DO), LED44.2 (DI)
unnamed: LED44.4 (DO), LED45.2 (DI)
unnamed: LED45.4 (DO), LED46.2 (DI)
unnamed: LED46.4 (DO), LED47.2 (DI)
unnamed: LED47.4 (DO), LED48.2 (DI)
unnamed: LED48.4 (DO), LED49.2 (DI)
unnamed: LED49.4 (DO), LED50.2 (DI)
unnamed: LED51.4 (DO), LED52.2 (DI)
unnamed: LED52.4 (DO), LED53.2 (DI)
unnamed: LED53.4 (DO), LED54.2 (DI)
unnamed: LED54.4 (DO), LED55.2 (DI)
unnamed: LED55.4 (DO), LED56.2 (DI)
unnamed: LED56.4 (DO), LED57.2 (DI)
unnamed: LED57.4 (DO), LED58.2 (DI)
unnamed: LED58.4 (DO), LED59.2 (DI)
unnamed: LED59.4 (DO), LED60.2 (DI)
unnamed: LED61.4 (DO), LED62.2 (DI)
unnamed: LED62.4 (DO), LED63.2 (DI)
unnamed: LED63.4 (DO), LED64.2 (DI)
unnamed: LED64.4 (DO), LED65.2 (DI)
unnamed: LED65.4 (DO), LED66.2 (DI)
unnamed: LED66.4 (DO), LED67.2 (DI)
unnamed: LED67.4 (DO), LED68.2 (DI)
ROW2: LED10.4 (DO), LED11.2 (DI)
ROW3: LED20.4 (DO), LED21.2 (DI)
ROW4: LED30.4 (DO), LED31.2 (DI)
ROW5: LED40.4 (DO), LED41.2 (DI)
ROW6: LED50.4 (DO), LED51.2 (DI)
ROW7: LED60.4 (DO), LED61.2 (DI)

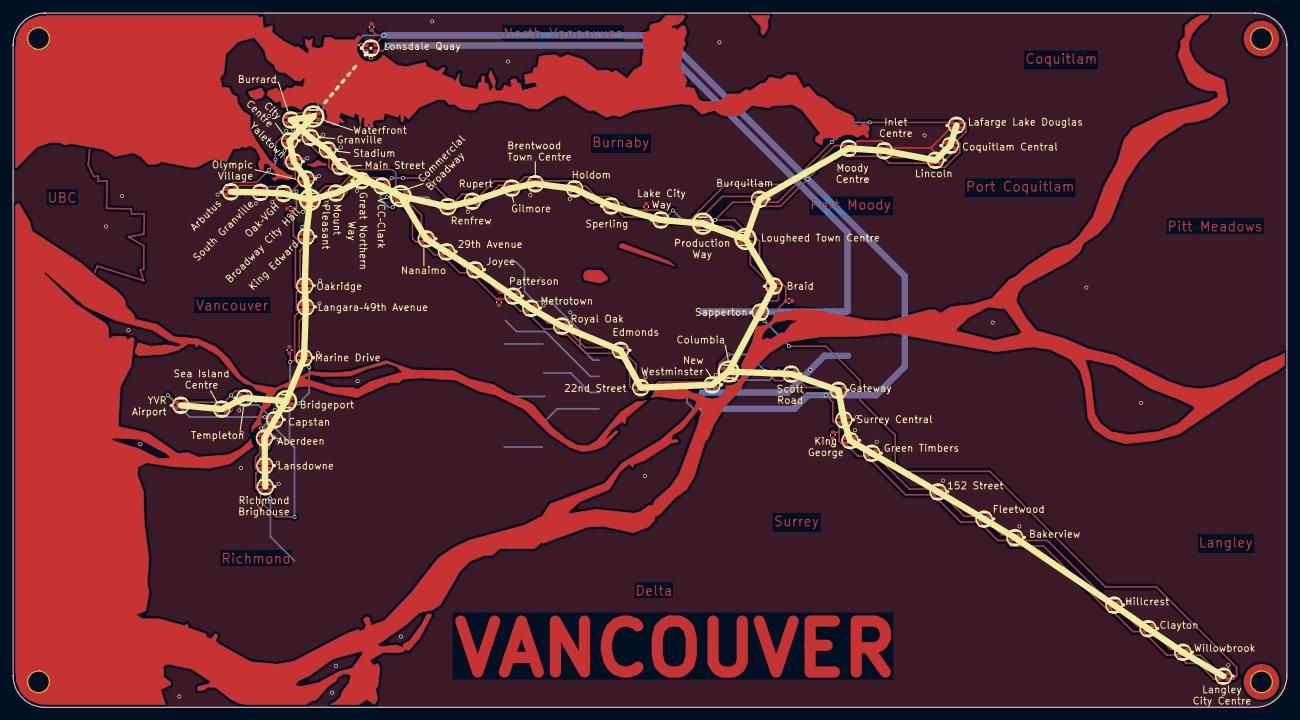
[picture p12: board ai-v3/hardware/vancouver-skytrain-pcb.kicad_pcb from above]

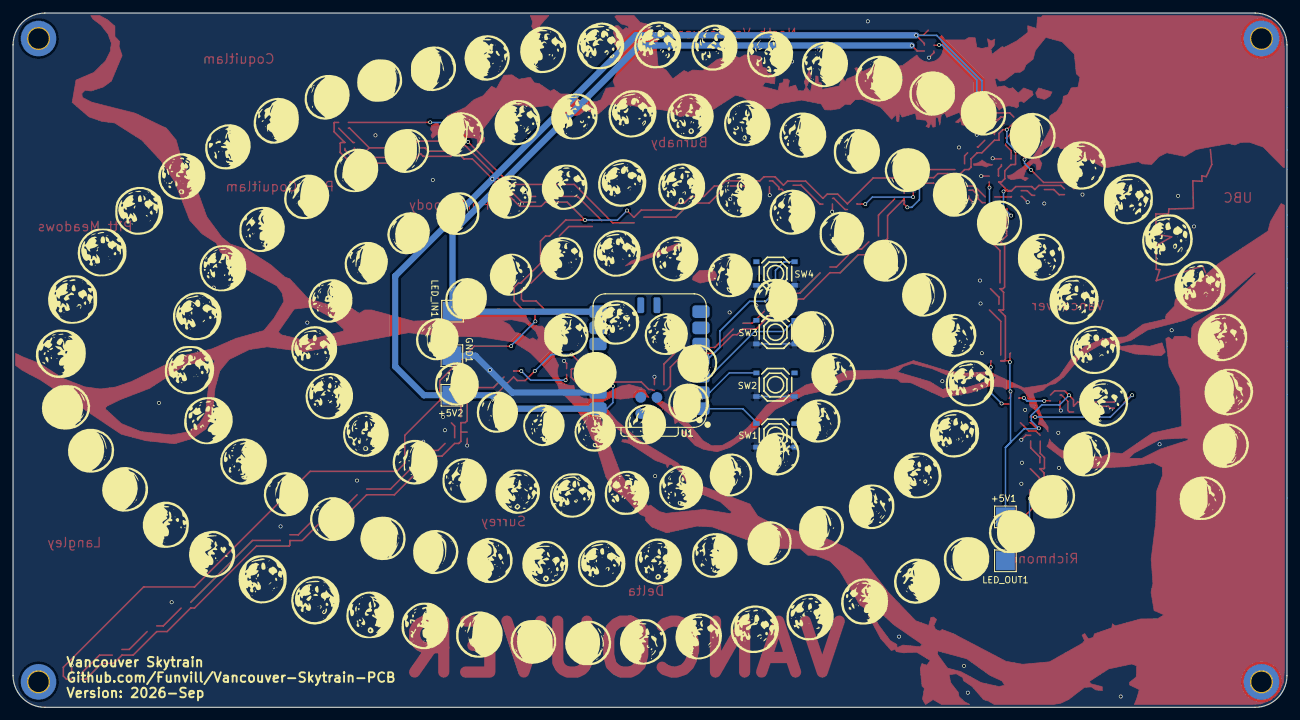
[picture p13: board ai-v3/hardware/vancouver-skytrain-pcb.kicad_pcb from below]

Board: 2 copper layers, 200.0 x 109.0 mm, 90 parts (10 on the bottom side), 75 nets.

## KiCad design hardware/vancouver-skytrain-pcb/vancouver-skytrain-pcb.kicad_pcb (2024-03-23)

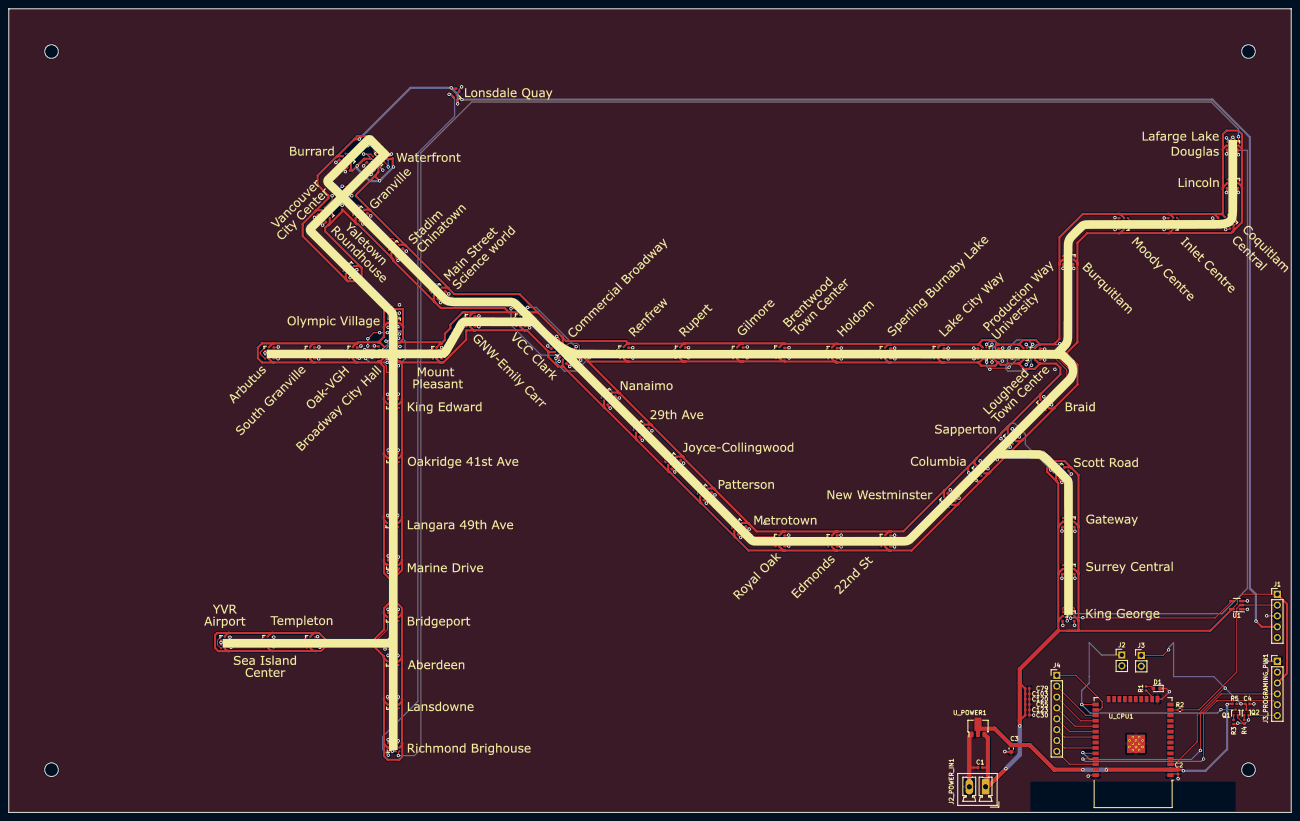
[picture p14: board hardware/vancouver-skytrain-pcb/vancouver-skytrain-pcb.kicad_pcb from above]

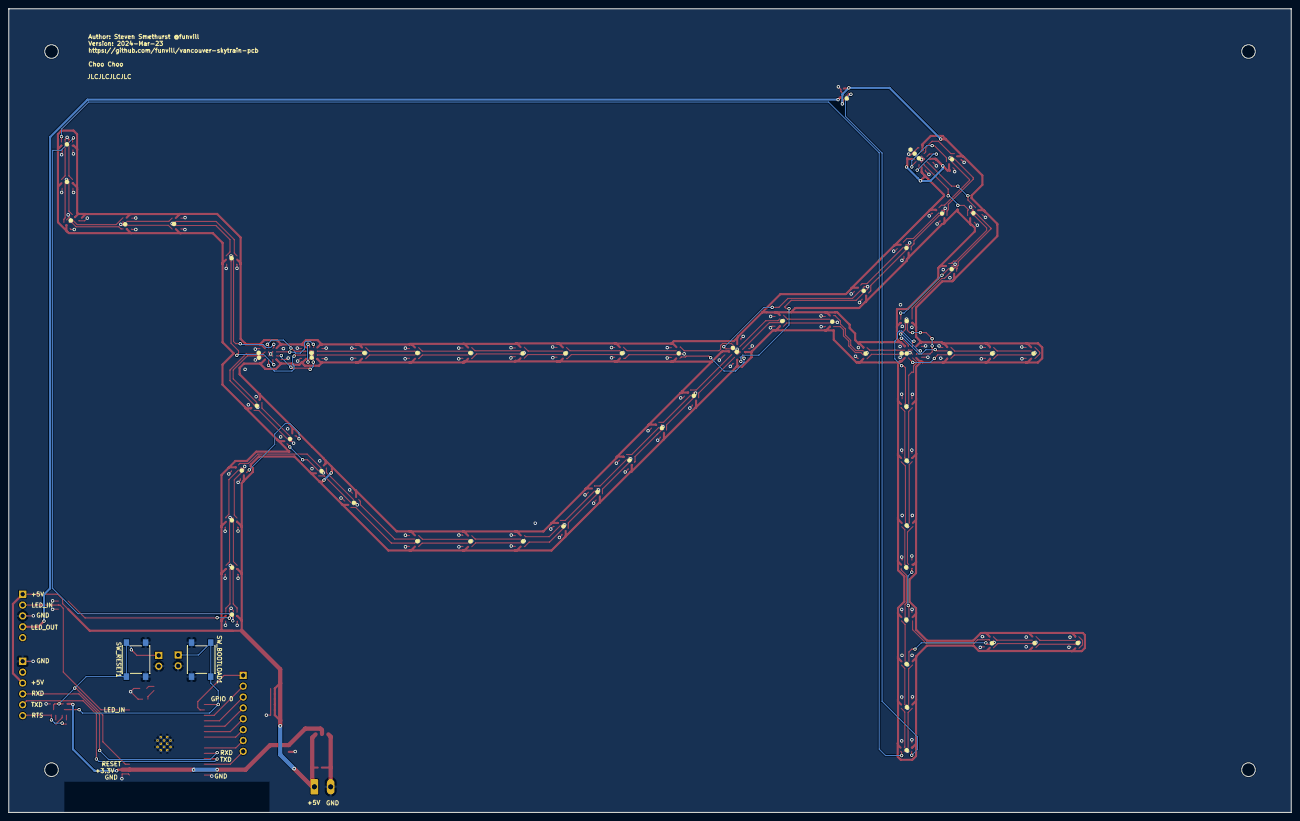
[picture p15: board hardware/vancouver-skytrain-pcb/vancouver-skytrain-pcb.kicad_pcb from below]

Board: 2 copper layers, 300.0 x 188.0 mm, 287 parts (2 on the bottom side), 151 nets.

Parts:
C1, C2, C4, C5, C6, C7, C8, C9, C10, C11, C12, C13, C14, C15, C16, C17, C18, C19, C20, C21, C22, C23, C24, C25, C26, C27, C28, C29, C30, C31, C32, C33, C34, C35, C36, C37, C38, C39, C40, C41, C42, C43, C44, C45, C46, C47, C48, C49, C50, C51, C52, C53, C54, C55, C56, C57, C58, C59, C60, C61, C62, C63, C64, C65, C66, C67, C68, C69, C70, C71, C72, C73, C74, C75, C76, C77, C78, C79, C80, C81, C82, C83, C84, C85, C86, C87, C88, C89, C90, C91, C92, C93, C94, C95, C96, C97, C98, C99, C100, C101, C102, C103, C104, C105, C106, C107, C108, C109, C110, C111, C112, C113, C114, C115, C116, C117, C118, C119, C120, C121, C122, C123, C124, C125, C126, C127, C128, C129, C130, C131, C132, C133, C134, C135, C136, C138: 1uF,25V,X5R; C_0402_1005Metric
C3: 10uF,10V,X5R; C_0603_1608Metric
D1: STATUS_LED; LED_0603_1608Metric
H1, H2, H3, H4: MountingHole; MountingHole_3.2mm_M3
J1: Conn_01x04; PinHeader_1x05_P2.54mm_Vertical
J2, J3: Conn_01x02; PinHeader_1x02_P2.54mm_Vertical
J2_POWER_IN1: Conn_01x02; PhoenixContact_MCV_1,5_2-G-3.81_1x02_P3.81mm_Vertical
J3_PROGRAMING_PIN1: Conn_01x06; PinHeader_1x06_P2.54mm_Vertical
J4: Conn_01x09; PinHeader_1x08_P2.54mm_Vertical
LED1, LED2, LED3, LED4, LED5, LED6, LED7, LED8, LED9, LED10, LED11, LED12, LED13, LED14, LED15, LED16, LED17, LED18, LED19, LED20, LED21, LED22, LED23, LED24, LED25, LED26, LED27, LED28, LED29, LED30, LED31, LED32, LED33, LED34, LED35, LED36, LED37, LED38, LED39, LED40, LED41, LED42, LED43, LED44, LED45, LED46, LED47, LED48, LED49, LED50, LED51, LED52, LED53, LED54, LED55, LED56, LED57, LED58, LED59, LED60, LED61, LED62, LED63, LED64, LED65, LED66, LED67, LED68, LED69, LED70, LED71, LED72, LED73, LED74, LED75, LED76, LED77, LED78, LED79, LED80, LED81, LED82, LED83, LED84, LED85, LED86, LED87, LED88, LED89, LED90, LED91, LED92, LED93, LED94, LED95, LED96, LED97, LED98, LED99, LED100, LED101, LED102, LED103, LED104, LED105, LED106, LED107, LED108, LED109, LED110, LED111, LED112, LED113, LED114, LED115, LED116, LED117, LED118, LED119, LED120, LED121, LED122, LED123, LED124, LED125, LED126, LED127: WS2812B; XL-1010RGBC-WS2812B
Q1, Q2: PN2222A; SOT-416
R1: 1k; C_0402_1005Metric
R2: 0; R_0402_1005Metric
R3, R4, R5: 10k; C_0402_1005Metric
SW_BOOTLOAD1: Switch_SW_Push; SW_Push_1P1T_NO_6x6mm_H9.5mm
SW_RESET1: Switch_SW_Push; SW_Push_1P1T_NO_6x6mm_H9.5mm
U1: 74AHC1G125; SOT-23-5
U_CPU1: ESP32-WROOM-32E; ESP32-WROOM-32
U_POWER1: UR133AG-33-AB3-C-R__3.3v; SOT-89-3

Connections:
+3.3V: C2.1, C3.1, R5.2, U_CPU1.2 (VDD), U_POWER1.2 (VO)
+5V: C1.1, C5.1, C6.1, C7.1, C8.1, C9.1, C10.1, C11.1, C12.1, C13.1, C14.1, C15.1, C16.1, C17.1, C18.1, C19.1, C20.1, C21.1, C22.1, C23.1, C24.1, C25.1, C26.1, C27.1, C28.1, C29.1, C30.1, C31.1, C32.1, C33.1, C34.1, C35.1, C36.1, C37.1, C38.1, C39.1, C40.1, C41.1, C42.1, C43.1, C44.1, C45.1, C46.1, C47.1, C48.1, C49.1, C50.1, C51.1, C52.1, C53.1, C54.1, C55.1, C56.1, C57.1, C58.1, C59.1, C60.1, C61.1, C62.1, C63.1, C64.1, C65.1, C66.1, C67.1, C68.1, C69.1, C70.1, C71.1, C72.1, C73.1, C74.1, C75.1, C76.1, C77.1, C78.1, C79.1, C80.1, C81.1, C82.1, C83.1, C84.1, C85.1, C86.1, C87.1, C88.1, C89.1, C90.1, C91.1, C92.1, C93.1, C94.1, C95.1, C96.1, C97.1, C98.1, C99.1, C100.1, C101.1, C102.1, C103.1, C104.1, C105.1, C106.1, C107.1, C108.1, C109.1, C110.1, C111.1, C112.1, C113.1, C114.1, C115.1, C116.1, C117.1, C118.1, C119.1, C120.1, C121.1, C122.1, C123.1, C124.1, C125.1, C126.1, C127.1, C128.1, C129.1, C130.1, C131.1, C132.1, C133.1, C134.1, C135.1, C136.1, C138.1, J1.1, J2_POWER_IN1.1, J3_PROGRAMING_PIN1.3, LED1.2 (VDD), LED2.2 (VDD), LED3.2 (VDD), LED4.2 (VDD), LED5.2 (VDD), LED6.2 (VDD), LED7.2 (VDD), LED8.2 (VDD), LED9.2 (VDD), LED10.2 (VDD), LED11.2 (VDD), LED12.2 (VDD), LED13.2 (VDD), LED14.2 (VDD), LED15.2 (VDD), LED16.2 (VDD), LED17.2 (VDD), LED18.2 (VDD), LED19.2 (VDD), LED20.2 (VDD), LED21.2 (VDD), LED22.2 (VDD), LED23.2 (VDD), LED24.2 (VDD), LED25.2 (VDD), LED26.2 (VDD), LED27.2 (VDD), LED28.2 (VDD), LED29.2 (VDD), LED30.2 (VDD), LED31.2 (VDD), LED32.2 (VDD), LED33.2 (VDD), LED34.2 (VDD), LED35.2 (VDD), LED36.2 (VDD), LED37.2 (VDD), LED38.2 (VDD), LED39.2 (VDD), LED40.2 (VDD), LED41.2 (VDD), LED42.2 (VDD), LED43.2 (VDD), LED44.2 (VDD), LED45.2 (VDD), LED46.2 (VDD), LED47.2 (VDD), LED48.2 (VDD), LED49.2 (VDD), LED50.2 (VDD), LED51.2 (VDD), LED52.2 (VDD), LED53.2 (VDD), LED54.2 (VDD), LED55.2 (VDD), LED56.2 (VDD), LED57.2 (VDD), LED58.2 (VDD), LED59.2 (VDD), LED60.2 (VDD), LED61.2 (VDD), LED62.2 (VDD), LED63.2 (VDD), LED64.2 (VDD), LED65.2 (VDD), LED66.2 (VDD), LED67.2 (VDD), LED68.2 (VDD), LED69.2 (VDD), LED70.2 (VDD), LED71.2 (VDD), LED72.2 (VDD), LED73.2 (VDD), LED74.2 (VDD), LED75.2 (VDD), LED76.2 (VDD), LED77.2 (VDD), LED78.2 (VDD), LED79.2 (VDD), LED80.2 (VDD), LED81.2 (VDD), LED82.2 (VDD), LED83.2 (VDD), LED84.2 (VDD), LED85.2 (VDD), LED86.2 (VDD), LED87.2 (VDD), LED88.2 (VDD), LED89.2 (VDD), LED90.2 (VDD), LED91.2 (VDD), LED92.2 (VDD), LED93.2 (VDD), LED94.2 (VDD), LED95.2 (VDD), LED96.2 (VDD), LED97.2 (VDD), LED98.2 (VDD), LED99.2 (VDD), LED100.2 (VDD), LED101.2 (VDD), LED102.2 (VDD), LED103.2 (VDD), LED104.2 (VDD), LED105.2 (VDD), LED106.2 (VDD), LED107.2 (VDD), LED108.2 (VDD), LED109.2 (VDD), LED110.2 (VDD), LED111.2 (VDD), LED112.2 (VDD), LED113.2 (VDD), LED114.2 (VDD), LED115.2 (VDD), LED116.2 (VDD), LED117.2 (VDD), LED118.2 (VDD), LED119.2 (VDD), LED120.2 (VDD), LED121.2 (VDD), LED122.2 (VDD), LED123.2 (VDD), LED124.2 (VDD), LED125.2 (VDD), LED126.2 (VDD), LED127.2 (VDD), U1.5 (VCC), U_POWER1.3 (VI)
/DTR: Q1.2 (E), R4.1
/GPIO0: J2.1, Q1.3 (C), SW_BOOTLOAD1.1 (A), U_CPU1.25 (IO0)
/PIN_LED_STATUS: R1.2, U_CPU1.16 (IO13)
/RESET: C4.1, J3.1, Q2.3 (C), R5.1, SW_RESET1.1 (A), U_CPU1.3 (EN)
/RTS: J3_PROGRAMING_PIN1.6, Q2.2 (E), R3.1
/RXD: J3_PROGRAMING_PIN1.4, U_CPU1.34 (RXD0/IO3)
/TXD: J3_PROGRAMING_PIN1.5, U_CPU1.35 (TXD0/IO1)
GND: C1.2, C2.2, C3.2, C4.2, C5.2, C6.2, C7.2, C8.2, C9.2, C10.2, C11.2, C12.2, C13.2, C14.2, C15.2, C16.2, C17.2, C18.2, C19.2, C20.2, C21.2, C22.2, C23.2, C24.2, C25.2, C26.2, C27.2, C28.2, C29.2, C30.2, C31.2, C32.2, C33.2, C34.2, C35.2, C36.2, C37.2, C38.2, C39.2, C40.2, C41.2, C42.2, C43.2, C44.2, C45.2, C46.2, C47.2, C48.2, C49.2, C50.2, C51.2, C52.2, C53.2, C54.2, C55.2, C56.2, C57.2, C58.2, C59.2, C60.2, C61.2, C62.2, C63.2, C64.2, C65.2, C66.2, C67.2, C68.2, C69.2, C70.2, C71.2, C72.2, C73.2, C74.2, C75.2, C76.2, C77.2, C78.2, C79.2, C80.2, C81.2, C82.2, C83.2, C84.2, C85.2, C86.2, C87.2, C88.2, C89.2, C90.2, C91.2, C92.2, C93.2, C94.2, C95.2, C96.2, C97.2, C98.2, C99.2, C100.2, C101.2, C102.2, C103.2, C104.2, C105.2, C106.2, C107.2, C108.2, C109.2, C110.2, C111.2, C112.2, C113.2, C114.2, C115.2, C116.2, C117.2, C118.2, C119.2, C120.2, C121.2, C122.2, C123.2, C124.2, C125.2, C126.2, C127.2, C128.2, C129.2, C130.2, C131.2, C132.2, C133.2, C134.2, C135.2, C136.2, C138.2, D1.1 (K), J1.3, J2.2, J2_POWER_IN1.2, J3.2, J3_PROGRAMING_PIN1.1, LED1.3 (VSS), LED2.3 (VSS), LED3.3 (VSS), LED4.3 (VSS), LED5.3 (VSS), LED6.3 (VSS), LED7.3 (VSS), LED8.3 (VSS), LED9.3 (VSS), LED10.3 (VSS), LED11.3 (VSS), LED12.3 (VSS), LED13.3 (VSS), LED14.3 (VSS), LED15.3 (VSS), LED16.3 (VSS), LED17.3 (VSS), LED18.3 (VSS), LED19.3 (VSS), LED20.3 (VSS), LED21.3 (VSS), LED22.3 (VSS), LED23.3 (VSS), LED24.3 (VSS), LED25.3 (VSS), LED26.3 (VSS), LED27.3 (VSS), LED28.3 (VSS), LED29.3 (VSS), LED30.3 (VSS), LED31.3 (VSS), LED32.3 (VSS), LED33.3 (VSS), LED34.3 (VSS), LED35.3 (VSS), LED36.3 (VSS), LED37.3 (VSS), LED38.3 (VSS), LED39.3 (VSS), LED40.3 (VSS), LED41.3 (VSS), LED42.3 (VSS), LED43.3 (VSS), LED44.3 (VSS), LED45.3 (VSS), LED46.3 (VSS), LED47.3 (VSS), LED48.3 (VSS), LED49.3 (VSS), LED50.3 (VSS), LED51.3 (VSS), LED52.3 (VSS), LED53.3 (VSS), LED54.3 (VSS), LED55.3 (VSS), LED56.3 (VSS), LED57.3 (VSS), LED58.3 (VSS), LED59.3 (VSS), LED60.3 (VSS), LED61.3 (VSS), LED62.3 (VSS), LED63.3 (VSS), LED64.3 (VSS), LED65.3 (VSS), LED66.3 (VSS), LED67.3 (VSS), LED68.3 (VSS), LED69.3 (VSS), LED70.3 (VSS), LED71.3 (VSS), LED72.3 (VSS), LED73.3 (VSS), LED74.3 (VSS), LED75.3 (VSS), LED76.3 (VSS), LED77.3 (VSS), LED78.3 (VSS), LED79.3 (VSS), LED80.3 (VSS), LED81.3 (VSS), LED82.3 (VSS), LED83.3 (VSS), LED84.3 (VSS), LED85.3 (VSS), LED86.3 (VSS), LED87.3 (VSS), LED88.3 (VSS), LED89.3 (VSS), LED90.3 (VSS), LED91.3 (VSS), LED92.3 (VSS), LED93.3 (VSS), LED94.3 (VSS), LED95.3 (VSS), LED96.3 (VSS), LED97.3 (VSS), LED98.3 (VSS), LED99.3 (VSS), LED100.3 (VSS), LED101.3 (VSS), LED102.3 (VSS), LED103.3 (VSS), LED104.3 (VSS), LED105.3 (VSS), LED106.3 (VSS), LED107.3 (VSS), LED108.3 (VSS), LED109.3 (VSS), LED110.3 (VSS), LED111.3 (VSS), LED112.3 (VSS), LED113.3 (VSS), LED114.3 (VSS), LED115.3 (VSS), LED116.3 (VSS), LED117.3 (VSS), LED118.3 (VSS), LED119.3 (VSS), LED120.3 (VSS), LED121.3 (VSS), LED122.3 (VSS), LED123.3 (VSS), LED124.3 (VSS), LED125.3 (VSS), LED126.3 (VSS), LED127.3 (VSS), SW_BOOTLOAD1.2 (B), SW_RESET1.2 (B), U1.1, U1.3 (GND), U_CPU1.1 (GND), U_CPU1.15 (GND), U_CPU1.38 (GND), U_CPU1.39 (GND), U_POWER1.1 (GND)
LEDS_CANADA_LINE_NORTH_TO_SOUTH: LED110.1 (DOUT), LED111.4 (DIN)
LEDS_CANADA_LINE_SOUTH_TO_NORTH: LED94.1 (DOUT), LED95.4 (DIN)
LEDS_EXPO_LINE_EAST_TO_WEST: J1.5, LED1.4 (DIN), U1.4
LEDS_EXPO_LINE_WEST_TO_EAST: LED24.1 (DOUT), LED25.4 (DIN)
LEDS_MILLENNIUM_LINE_EAST_TO_WEST: LED48.1 (DOUT), LED49.4 (DIN)
LEDS_MILLENNIUM_LINE_WEST_TO_EAST: LED71.1 (DOUT), LED72.4 (DIN)
LEDS_SEA_BUS: LED126.1 (DOUT), LED127.4 (DIN)
LED_IN: J1.2, R2.2, U1.2
LED_OUT: J1.4, LED127.1 (DOUT)
unnamed: D1.2 (A), R1.1
unnamed: LED1.1 (DOUT), LED2.4 (DIN)
unnamed: LED2.1 (DOUT), LED3.4 (DIN)
unnamed: LED3.1 (DOUT), LED4.4 (DIN)
unnamed: LED4.1 (DOUT), LED5.4 (DIN)
unnamed: LED5.1 (DOUT), LED6.4 (DIN)
unnamed: LED6.1 (DOUT), LED7.4 (DIN)
unnamed: LED7.1 (DOUT), LED8.4 (DIN)
unnamed: LED8.1 (DOUT), LED9.4 (DIN)
unnamed: LED9.1 (DOUT), LED10.4 (DIN)
unnamed: LED10.1 (DOUT), LED11.4 (DIN)
unnamed: LED11.1 (DOUT), LED12.4 (DIN)
unnamed: LED12.1 (DOUT), LED13.4 (DIN)
unnamed: LED13.1 (DOUT), LED14.4 (DIN)
unnamed: LED14.1 (DOUT), LED15.4 (DIN)
unnamed: LED15.1 (DOUT), LED16.4 (DIN)
unnamed: LED16.1 (DOUT), LED17.4 (DIN)
unnamed: LED17.1 (DOUT), LED18.4 (DIN)
unnamed: LED18.1 (DOUT), LED19.4 (DIN)
unnamed: LED19.1 (DOUT), LED20.4 (DIN)
unnamed: LED20.1 (DOUT), LED21.4 (DIN)
unnamed: LED21.1 (DOUT), LED22.4 (DIN)
unnamed: LED22.1 (DOUT), LED23.4 (DIN)
unnamed: LED23.1 (DOUT), LED24.4 (DIN)
unnamed: LED25.1 (DOUT), LED26.4 (DIN)
unnamed: LED26.1 (DOUT), LED27.4 (DIN)
unnamed: LED27.1 (DOUT), LED28.4 (DIN)
unnamed: LED28.1 (DOUT), LED29.4 (DIN)
unnamed: LED29.1 (DOUT), LED30.4 (DIN)
unnamed: LED30.1 (DOUT), LED31.4 (DIN)
unnamed: LED31.1 (DOUT), LED32.4 (DIN)
unnamed: LED32.1 (DOUT), LED33.4 (DIN)
unnamed: LED33.1 (DOUT), LED34.4 (DIN)
unnamed: LED34.1 (DOUT), LED35.4 (DIN)
unnamed: LED35.1 (DOUT), LED36.4 (DIN)
unnamed: LED36.1 (DOUT), LED37.4 (DIN)
unnamed: LED37.1 (DOUT), LED38.4 (DIN)
unnamed: LED38.1 (DOUT), LED39.4 (DIN)
unnamed: LED39.1 (DOUT), LED40.4 (DIN)
unnamed: LED40.1 (DOUT), LED41.4 (DIN)
unnamed: LED41.1 (DOUT), LED42.4 (DIN)
unnamed: LED42.1 (DOUT), LED43.4 (DIN)
unnamed: LED43.1 (DOUT), LED44.4 (DIN)
unnamed: LED44.1 (DOUT), LED45.4 (DIN)
unnamed: LED45.1 (DOUT), LED46.4 (DIN)
unnamed: LED46.1 (DOUT), LED47.4 (DIN)
unnamed: LED47.1 (DOUT), LED48.4 (DIN)
unnamed: LED49.1 (DOUT), LED50.4 (DIN)
unnamed: LED50.1 (DOUT), LED51.4 (DIN)
unnamed: LED51.1 (DOUT), LED52.4 (DIN)
unnamed: LED52.1 (DOUT), LED53.4 (DIN)
unnamed: LED53.1 (DOUT), LED54.4 (DIN)
unnamed: LED54.1 (DOUT), LED55.4 (DIN)
unnamed: LED55.1 (DOUT), LED56.4 (DIN)
unnamed: LED56.1 (DOUT), LED57.4 (DIN)
unnamed: LED57.1 (DOUT), LED58.4 (DIN)
unnamed: LED58.1 (DOUT), LED59.4 (DIN)
unnamed: LED59.1 (DOUT), LED60.4 (DIN)
unnamed: LED60.1 (DOUT), LED61.4 (DIN)
unnamed: LED61.1 (DOUT), LED62.4 (DIN)
unnamed: LED62.1 (DOUT), LED63.4 (DIN)
unnamed: LED63.1 (DOUT), LED64.4 (DIN)
unnamed: LED64.1 (DOUT), LED65.4 (DIN)
unnamed: LED65.1 (DOUT), LED66.4 (DIN)
unnamed: LED66.1 (DOUT), LED67.4 (DIN)
unnamed: LED67.1 (DOUT), LED68.4 (DIN)
unnamed: LED68.1 (DOUT), LED69.4 (DIN)
unnamed: LED69.1 (DOUT), LED70.4 (DIN)
unnamed: LED70.1 (DOUT), LED71.4 (DIN)
unnamed: LED72.1 (DOUT), LED73.4 (DIN)
unnamed: LED73.1 (DOUT), LED74.4 (DIN)
unnamed: LED74.1 (DOUT), LED75.4 (DIN)
unnamed: LED75.1 (DOUT), LED76.4 (DIN)
unnamed: LED76.1 (DOUT), LED77.4 (DIN)
unnamed: LED77.1 (DOUT), LED78.4 (DIN)
unnamed: LED78.1 (DOUT), LED79.4 (DIN)
unnamed: LED79.1 (DOUT), LED80.4 (DIN)
unnamed: LED80.1 (DOUT), LED81.4 (DIN)
unnamed: LED81.1 (DOUT), LED82.4 (DIN)
unnamed: LED82.1 (DOUT), LED83.4 (DIN)
unnamed: LED83.1 (DOUT), LED84.4 (DIN)
unnamed: LED84.1 (DOUT), LED85.4 (DIN)
unnamed: LED85.1 (DOUT), LED86.4 (DIN)
unnamed: LED86.1 (DOUT), LED87.4 (DIN)
unnamed: LED87.1 (DOUT), LED88.4 (DIN)
unnamed: LED88.1 (DOUT), LED89.4 (DIN)
unnamed: LED89.1 (DOUT), LED90.4 (DIN)
unnamed: LED90.1 (DOUT), LED91.4 (DIN)
unnamed: LED91.1 (DOUT), LED92.4 (DIN)
unnamed: LED92.1 (DOUT), LED93.4 (DIN)
unnamed: LED93.1 (DOUT), LED94.4 (DIN)
unnamed: LED95.1 (DOUT), LED96.4 (DIN)
unnamed: LED96.1 (DOUT), LED97.4 (DIN)
unnamed: LED97.1 (DOUT), LED98.4 (DIN)
unnamed: LED98.1 (DOUT), LED99.4 (DIN)
unnamed: LED99.1 (DOUT), LED100.4 (DIN)
unnamed: LED100.1 (DOUT), LED101.4 (DIN)
unnamed: LED101.1 (DOUT), LED102.4 (DIN)
unnamed: LED102.1 (DOUT), LED103.4 (DIN)
unnamed: LED103.1 (DOUT), LED104.4 (DIN)
unnamed: LED104.1 (DOUT), LED105.4 (DIN)
unnamed: LED105.1 (DOUT), LED106.4 (DIN)
unnamed: LED106.1 (DOUT), LED107.4 (DIN)
unnamed: LED107.1 (DOUT), LED108.4 (DIN)
unnamed: LED108.1 (DOUT), LED109.4 (DIN)
unnamed: LED109.1 (DOUT), LED110.4 (DIN)
unnamed: LED111.1 (DOUT), LED112.4 (DIN)
unnamed: LED112.1 (DOUT), LED113.4 (DIN)
unnamed: LED113.1 (DOUT), LED114.4 (DIN)
unnamed: LED114.1 (DOUT), LED115.4 (DIN)
unnamed: LED115.1 (DOUT), LED116.4 (DIN)
unnamed: LED116.1 (DOUT), LED117.4 (DIN)
unnamed: LED117.1 (DOUT), LED118.4 (DIN)
unnamed: LED118.1 (DOUT), LED119.4 (DIN)
unnamed: LED119.1 (DOUT), LED120.4 (DIN)
unnamed: LED120.1 (DOUT), LED121.4 (DIN)
unnamed: LED121.1 (DOUT), LED122.4 (DIN)
unnamed: LED122.1 (DOUT), LED123.4 (DIN)
unnamed: LED123.1 (DOUT), LED124.4 (DIN)
unnamed: LED124.1 (DOUT), LED125.4 (DIN)
unnamed: LED125.1 (DOUT), LED126.4 (DIN)
unnamed: Q1.1 (B), R3.2
unnamed: Q2.1 (B), R4.2
unnamed: R2.1, U_CPU1.13 (IO14)
Pin26: J4.1, U_CPU1.26 (IO4)
Pin27: J4.2, U_CPU1.27 (IO16)
Pin28: J4.3, U_CPU1.28 (IO17)
Pin29: J4.4, U_CPU1.29 (IO5)
Pin30: J4.5, U_CPU1.30 (IO18)
Pin31: J4.6, U_CPU1.31 (IO19)
Pin33: J4.7, U_CPU1.33 (IO21)
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

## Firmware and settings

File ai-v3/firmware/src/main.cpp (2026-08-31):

// Vancouver SkyTrain LED map - v3 firmware
// One WS2812B (XL-1615RGBC) per station, 68 LEDs total.
// Index tables are GENERATED from ai-v3/input/vancouver.json by
// tools/export_placement.py -> include/firmware_tables.h. Regenerate after
// any layout/chain change; never edit the tables by hand.
//
// Board: XIAO RP2040 on the back (DNP footprint).
//   D0 -> 74AHC1G125 -> LED data chain
//   D1..D4 -> buttons SW1..SW4 (DNP), active low, internal pull-ups

#include <Arduino.h>
#include "FastLED.h"
#include "firmware_tables.h"

const int PIN_LED_DATA = D0;
const int PIN_BTN_MODE = D1;
const int PIN_BTN_BRIGHT = D2;
const int PIN_BTN_SPEED = D3;
const int PIN_BTN_LINE = D4;
const uint32_t BAUD_RATE = 115200;
const uint8_t BUILD_NUMBER = 1;

CRGB leds[NUM_LEDS];

uint8_t brightness = 48;
uint16_t stepMs = 700;          // train advance interval
const uint8_t FADE_PER_FRAME = 24;

// TransLink line colours
const CRGB COLOR_EXPO = CRGB(0x00, 0x5D, 0xAA);
const CRGB COLOR_MILLENNIUM = CRGB(0xFD, 0xD0, 0x05);
const CRGB COLOR_CANADA = CRGB(0x00, 0x9A, 0xC7);
const CRGB COLOR_SEABUS = CRGB(0xC0, 0xC0, 0xC0);

struct Route {
  const int *idx;    // LED index per station along the route
  int count;
  CRGB color;
  int trains;        // simultaneous trains on this route
  int pos[4];        // per-train station cursor (max 4 trains)
  int dir[4];        // +1 / -1
};

Route routes[] = {
  {LINE_EXPO_LANGLEY_CITY_CENTRE, LINE_EXPO_LANGLEY_CITY_CENTRE_COUNT,
   COLOR_EXPO, 3, {0}, {0}},
  {LINE_EXPO_PRODUCTION_WAY, LINE_EXPO_PRODUCTION_WAY_COUNT,
   COLOR_EXPO, 2, {0}, {0}},
  {LINE_MILLENNIUM, LINE_MILLENNIUM_COUNT, COLOR_MILLENNIUM, 3, {0}, {0}},
  {LINE_CANADA_YVR, LINE_CANADA_YVR_COUNT, COLOR_CANADA, 2, {0}, {0}},
  {LINE_CANADA_RICHMOND_BRIGHOUSE, LINE_CANADA_RICHMOND_BRIGHOUSE_COUNT,
   COLOR_CANADA, 2, {0}, {0}},
};
const int ROUTE_COUNT = sizeof(routes) / sizeof(routes[0]);

void setup() {
  Serial.begin(BAUD_RATE);
  Serial.println("SkyTrain map v3 build " + String(BUILD_NUMBER));

  pinMode(PIN_BTN_MODE, INPUT_PULLUP);
  pinMode(PIN_BTN_BRIGHT, INPUT_PULLUP);
  pinMode(PIN_BTN_SPEED, INPUT_PULLUP);
  pinMode(PIN_BTN_LINE, INPUT_PULLUP);

  FastLED.addLeds<NEOPIXEL, PIN_LED_DATA>(leds, NUM_LEDS);
  FastLED.setBrightness(brightness);
  // USB powered: hard cap regardless of brightness/animation choices
  FastLED.setMaxPowerInVoltsAndMilliamps(5, 1500);

  for (int r = 0; r < ROUTE_COUNT; r++) {
    for (int t = 0; t < routes[r].trains; t++) {
      routes[r].pos[t] = (routes[r].count * t) / routes[r].trains;
      routes[r].dir[t] = (t % 2 == 0) ? 1 : -1;
    }
  }
}

void advanceTrains() {
  for (int r = 0; r < ROUTE_COUNT; r++) {
    Route &rt = routes[r];
    for (int t = 0; t < rt.trains; t++) {
      rt.pos[t] += rt.dir[t];
      if (rt.pos[t] >= rt.count) {          // bounce at the terminus
        rt.pos[t] = rt.count - 2;
        rt.dir[t] = -1;
      } else if (rt.pos[t] < 0) {
        rt.pos[t] = 1;
        rt.dir[t] = 1;
      }
    }
  }
}

void handleButtons() {
  static uint32_t lastPress = 0;
  if (millis() - lastPress < 250) return;   // debounce
  if (digitalRead(PIN_BTN_BRIGHT) == LOW) {
    brightness = (brightness >= 224) ? 16 : brightness + 32;
    FastLED.setBrightness(brightness);
    lastPress = millis();
  }
  if (digitalRead(PIN_BTN_SPEED) == LOW) {
    stepMs = (stepMs <= 200) ? 1200 : stepMs - 200;
    lastPress = millis();
  }
  // PIN_BTN_MODE / PIN_BTN_LINE reserved for future animation modes
}

void loop() {
  handleButtons();

  EVERY_N_MILLISECONDS_I(trainTimer, 700) {
    trainTimer.setPeriod(stepMs);
    advanceTrains();
  }

  // fade trails, then draw trains at full line colour
  fadeToBlackBy(leds, NUM_LEDS, FADE_PER_FRAME);
  for (int r = 0; r < ROUTE_COUNT; r++) {
    Route &rt = routes[r];
    for (int t = 0; t < rt.trains; t++) {
      leds[rt.idx[rt.pos[t]]] = rt.color;
    }
  }
  // SeaBus: slow breathing pulse
  leds[LINE_SEABUS[0]] = COLOR_SEABUS;
  leds[LINE_SEABUS[0]].nscale8(beatsin8(6, 20, 255));

  FastLED.show();
  delay(16);
}

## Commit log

2023-06-03 First very rough version to check the placement of everything
    [vancouver-skytrain-pcb.kicad_pcb, vancouver-skytrain-pcb.kicad_sch]
2023-06-04 positioned all the LEDs, Cap, and 5v Rails
    [XL-1010RGBC-WS2812B.stp, vancouver-skytrain-pcb.kicad_pcb, vancouver-skytrain-pcb.kicad_sch]
2023-06-04 Ground pins
    [vancouver-skytrain-pcb.kicad_pcb]
2023-06-05 Resolved a bunch of DRC errors
    [vancouver-skytrain-pcb.kicad_pcb, vancouver-skytrain-pcb.kicad_sch]
2023-06-05 Added images to the readme
    [vancouver-skytrain-pcb.kicad_pcb]
2023-09-17 Clean up before sending to fab
    [vancouver-skytrain-pcb-B_Courtyard.gbr, vancouver-skytrain-pcb-B_Cu.gbr, vancouver-skytrain-pcb-B_Fab.gbr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]
2023-11-28 Added vancouver-skytrain-pcb - natrual
    [bom.csv, designators.csv, map2.kicad_pcb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]
2024-03-23 Updated headers and update to kicad v8
    [bom.csv, designators.csv, map.kicad_pcb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]
2024-03-24 Added test points for all leds that look like bugs
    [vancouver-skytrain-pcb.kicad_sch]
2024-03-24 Updating the parts that are DNP
    [bom.csv, designators.csv, positions.csv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]
2024-03-25 Cleaning up before submitting
    [bom.csv, designators.csv, positions.csv]
2025-02-07 Updated firmware to add more trains and better fading
    [vancouver-skytrain-pcb.kicad_sch]
2025-07-18 moved version 1 to the v1 folder
    [XL-1010RGBC-WS2812B.stp, bom.csv, designators.csv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]
2025-11-29 Starting on version 2
    [vancouver-skytrain-pcb.kicad_pcb]
2025-11-29 part placement
    [vancouver-skytrain-pcb.kicad_pcb, vancouver-skytrain-pcb.kicad_sch]
2026-08-31 ai-v3: plan, city-map pipeline, and 100mm text-fit test
    - docs: v3 plan, project review, station list, fit report
    - tools: city-agnostic JSON->SVG pipeline (citymap, render_map,
    check_fit, render_back) with data validation tests
    - input: vancouver.json - 67 stations + SeaBus, octilinear iconic
    layout, label placement, land/water geometry
    - test-results: rendered previews at 100/120/135/150mm + back side
    Fit test verdict: 100mm fails with full names (16 collisions @1.2mm
    text); 135mm recommended (clean with one short-name substitution).
2026-08-31 ai-v3: 150mm board, peninsula extension, sea/parks geography
    - Board size locked at 150x150mm per user decision
    - Network shifted 5mm east; west side now carries the Point Grey
    peninsula, English Bay, and Stanley Park
    - Sea outline traced from the v1 realistic map: Burrard Inlet with
    Port Moody arm, False Creek connected to English Bay, Fraser River,
    Sea Island and Lulu Island outlines
    - Parks: Stanley, Pacific Spirit, Queen Elizabeth, Central,
    Green Timbers, Burnaby Lake, Lafarge Lake
    - Surrey leg turns south at Bakerview; Coquitlam branch stepped
    down-left so right-side labels fit
    - Fit check: 0 collisions at 150mm, full names, 1.2mm text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
2026-08-31 ai-v3: placement/firmware exports, XIAO firmware, KiCad board seeded
    - export_placement.py: leds.csv (68 LEDs, chain order, positions at
    150mm, DOUT-facing rotations) + generated firmware_tables.h; chain
    order stored in vancouver.json; longest data hop 64mm
    - firmware/: adapted from v1 for XIAO RP2040 (earlephilhower core),
    generated index tables, FastLED power cap 5V/1.5A, 4 buttons on
    D1-D4, SeaBus breathing pulse; builds clean (2% flash)
    - hardware/: v2 KiCad project copied; reposition_board.py rewrote all
    68 LED positions to the new map, centered U1 (XIAO) with SW1-SW4
    flanking, replaced outline with 150x150mm r5 rounded square, removed
    stale v2 art; validated via kicad-cli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
    [leds.csv, vancouver-skytrain-pcb.kicad_pcb, vancouver-skytrain-pcb.kicad_sch]
2026-08-31 ai-v3: generate station labels and land/water art directly on the PCB
    - export_art.py: writes station-name silkscreen and land/water shapes
    straight into the .kicad_pcb (no Inkscape/svg2shenzhen step) -
    water as F.Cu+F.Mask exposed copper (v1's technique, generated
    instead of hand-drawn), parks/islands as F.SilkS outlines only.
    Idempotent via a per-run art-manifest so re-running after editing
    vancouver.json never leaves stale/duplicate art behind.
    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
    [vancouver-skytrain-pcb.kicad_pcb]
2026-08-31 ai-v3: render_board.py, redraw coastline to match real geography
    - render_board.py: renders board-top.png/board-bottom.png via KiCad
    9's native 3D renderer (kicad-cli pcb render), no browser needed.
    - Redrew every geo shape in vancouver.json against real Vancouver
    geography instead of the earlier coarse placeholder blobs: a
    jagged Burrard Inlet coastline with the Port Moody arm reaching
    toward Moody Centre/Inlet Centre, a proper False Creek between the
    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
    [leds.csv, vancouver-skytrain-pcb.kicad_pcb]
2026-08-31 ai-v3: draw transit lines on silkscreen, match TransLink map style
    Styled after TransLink's official 'Future Rapid Transit Network' map
    (user-supplied reference) - filled parks, labelled rivers/
    municipalities, and future segments visually distinct from the
    current network.
    - export_art.py route_blocks(): every line segment as an F.SilkS
    gr_line (1.0mm). Segments touching a future station (Broadway
    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
    [vancouver-skytrain-pcb.kicad_pcb]
2026-08-31 ai-v3: match geography to the official TransLink map, drop labels
    - Removed the municipality/river-name annotations added last pass
    (vancouver.json annotations list now empty) per request - the
    reusable code path stays for future cities that want it.
    - Redrew every geo shape by hand against TransLink's official
    Future Rapid Transit Network map (user-supplied reference), not
    invented: Point Grey now reads as its own peninsula (Pacific
    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
    [vancouver-skytrain-pcb.kicad_pcb]
2026-08-31 ai-v3: trace station positions and geography from the real PDF map
    Redoes both the station layout and land/water/park geometry from
    skytrain-network-map.pdf's actual vector content instead of the
    prior by-eye approximation - a real fix for the accuracy gap flagged
    last round.
    - input/match_stations.py: pdfplumber extracts every text label's
    exact (x,y); pymupdf extracts every station-dot circle, colour-
    coded by line (teal=Canada, blue=Expo, yellow=Millennium,
    navy=interchange/hub). Each station matched via one document-
    unique anchor word. Angled labels near line junctions
    (Commercial-Broadway, Lougheed, Sapperton, Lake City Way,
    VCC-Clark) came out garbled from pdfplumber's wo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
    [leds.csv, vancouver-skytrain-pcb.kicad_pcb]
2026-08-31 ai-v3: fix vertical stretch, auto-optimize label placement
    - build_vancouver_json.py / build_geo.py: replaced independent x/y
    scaling (which stretched the network to fill the square board,
    distorting every real angle from the PDF) with one uniform scale
    factor sized to the page width, top-aligned. The source map is
    wider than tall, so this leaves blank canvas at the bottom instead
    of stretching content vertically - proportions now match the PDF
    exactly except for the one physically-required exception: Waterfront/
    Burrard/Granville were nudged apart by ~0.4mm each (preserving their
    real line direction) since the real map draws them closer together
    than a 2.5mm LED pitch can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
    [leds.csv, vancouver-skytrain-pcb.kicad_pcb]
2026-08-31 ai-v3: straighten Broadway corridor, extend water to left edge, fix SeaBus
    - build_vancouver_json.py: the Broadway corridor (real Millennium
    trunk VCC-Clark..Lake City Way plus its future westward extension
    to Arbutus) is one straight street in reality - the row now stays
    on a single flat line at Broadway-City Hall's y (its fixed
    interchange point on the Canada Line column) instead of sloping
    down to meet it. Arbutus..VCC-Clark is computed as one continuous
    6-gap sequence with a single step size derived from the two real
    traced anchors (Broadway-City Hall, VCC-Clark), replacing the
    earlier two independently-anchored half-chains that could overlap.
    - build_geo.py: the source P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
    [leds.csv, vancouver-skytrain-pcb.kicad_pcb]
2026-08-31 ai-v3: restore Point Grey peninsula, bump version, fix pad overlap
    - build_geo.py: the west-coast water patch from two sessions ago
    paved straight over Point Grey (the real UBC/Kitsilano peninsula,
    right at Arbutus's latitude) with a flat rectangle, clipping it at
    the board edge instead of showing it. Carved a rounded cape shape
    back out of the patch - a real, well-known landform (not traced,
    since no station sits on it to anchor a PDF trace to, but not
    invented either).
    - hardware/vancouver-skytrain-pcb.kicad_pcb: bumped the back-silk
    version text from 2025-Nov-29 (stale, left over from v2) to
    2026-Aug-31.
    - tools/reposition_board.py: three test points (GND/+5V/LED_IN) were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
    [vancouver-skytrain-pcb.kicad_pcb]
2026-08-31 ai-v3: remove invented coastline patches, match the PDF exactly
    Re-checked the actual source PDF directly instead of assuming the
    gap in traced water was a tracing error. It isn't: the whole middle
    band down the west side of the map (Vancouver City Centre through
    Marine Drive) genuinely is solid land colour all the way to the page
    edge in the original - no coastline is drawn there at all, since
    that area (west of the Cambie corridor) is off the detail this
    particular map bothers with. Water only touches the left edge at the
    very top (English Bay/Burrard Inlet) and again near the bottom (Sea
    Island) - which the pure trace already got right, before either of
    the last two sessions' patches.
    -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
    [vancouver-skytrain-pcb.kicad_pcb]
2026-09-06 ai-v3: design-review pass - west coast, Delta, wordmark, readable labels
    Left edge now ends in water: build_geo.py carves the Point Grey tip out
    of the traced land in the PDF's own 45-degree idiom (the source draws no
    coastline west of Cambie; v2's look came from a wider frame, not from
    data), and the frame extends below the page so Delta / the South Arm /
    Boundary Bay fill the bottom third instead of blank soldermask.
    Map furniture: exposed-copper VANCOUVER wordmark (v2 style), 49th
    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
    [vancouver-skytrain-pcb.kicad_pcb]
2026-09-06 ai-v3: switch station layout and geography to the v1 natural map
    The TransLink schematic's 1.26:1 page stretched everything south of
    Broadway and turned the Fraser into a 45-degree band. Replace it with
    v1's natural-geography map (v1/input/natrual/map.svg): real coastline -
    Burrard Inlet with the North Shore, Point Grey, the Fraser's arms,
    Boundary Bay - and v1's station layout drawn over it.
    input/build_from_v1.py: stations = midpoints of v1's N/S LED pairs,
    mapped from the v1 board into the map's frame by a similarity fit
    (v1 rotated the map ~9 deg; we keep the map's orientation) and snapped
    to map.png's station dots where one is within 2.5 mm. Coastline parsed
    from the SVG (parse_v1_coas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
    [leds.csv, vancouver-skytrain-pcb.kicad_pcb]
2026-09-06 ai-v3: rebuild from OpenStreetMap - real shoreline, 150x86 board
    Station positions and geography now come from OSM (input/build_from_osm.py,
    Overpass responses cached in input/osm/): real station nodes; sea/inlet/
    Fraser arms from natural=coastline ways (land-on-the-left rule over
    polygonized faces); the Fraser main stem and Pitt River as buffered
    centrelines where the coastline stops; only the large named lakes
    (Burnaby, Deer, Trout, Como, Lost Lagoon...). Shoreline smoothed with a
    morphological open/close + simplify, small river islands filled, edge
    slivers dropped.
    Board is the frame's own aspect, 150 x 86.2 mm (canvas_h_mm, non-square
    support through citymap/check_fit/render_map/reposit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
    [leds.csv, vancouver-skytrain-pcb.kicad_pcb]
2026-09-07 ai-v3: geography from the BC Freshwater Atlas, standalone preview
    OSM's coastline in this box stops at Burrard Inlet - the Fraser's arms
    are riverbank polygons there, which the previous build never loaded, so
    Sea Island, Lulu Island and the whole estuary collapsed into land
    (test-results/geo-debug-faces.png shows the face votes).
    input/geo_fwa.py builds land/water from the province's 1:20k Freshwater
    Atlas via WFS, all as polygons: land = FWA watershed groups (they end at
    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
2026-09-08 ai-v3: crop the geography frame to the network, 200 x 109 mm
    Frame runs Point Grey to just past Langley City Centre and a sliver of
    North Shore above Lonsdale Quay to ~1 km below Langley: 46.2 x 25.2 km,
    200 x 109 mm at 4.33 mm/km. Lakes by name whitelist (Burnaby, Deer,
    Trout, Como, Lost Lagoon, Lafarge, Sasamat, Buntzen); river polygons
    kept only when their mean width is >= 100 m (drops creeks); bay tips
    mostly outside the frame dropped.
2026-09-08 ai-v3: FWA-based data build, board preview renderer, label annealing
    input/build_from_fwa.py assembles vancouver.json from the approved BC
    Freshwater Atlas geography (geo_fwa) and OSM station positions at
    200 x 109 mm (board_scale 2.0): stations nudged onto land, 3.3 mm pitch
    spreading, LED clearance disks, copper city-name labels auto-placed away
    from track/water/each other, VANCOUVER wordmark bottom-centre placed
    first. Only one boundary is drawn - UBC / University Endowment Lands,
    taken as the part of Vancouver's municipal boundary shared with no other
    municipality - with a UBC label on the peninsula.
    tools/preview_map.py renders the board (water, copper furniture, routes,
    rings, labels,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
2026-09-08 ai-v3: 200 x 109 mm board from the FWA/OSM data build
    Board regenerated at board_scale 2.0 from vancouver.json (BC Freshwater
    Atlas geography, OSM stations, copper city labels, UBC boundary,
    wordmark): placement, outline, art. Wordmark is shifted off the Fraser
    South Arm (KiCad's bold stroke font is ~0.95 x size per character, the
    estimate was 0.85). DRC: no clearance / edge / shorting violations; art
    regeneration idempotent; version 2026-Sep-07. Test margin and README run
    commands updated for the new scale. Station labels are left for hand
    placement in the PCB.
    [leds.csv, vancouver-skytrain-pcb.kicad_pcb]
2026-09-08 Updated labels
    [vancouver-skytrain-pcb.kicad_pcb]
2026-09-08 ai-v3: import hand-edited labels from the PCB back into the data
    tools/import_labels.py: every station label, leader line and annotation
    is found on the board by the exporter's deterministic uuid and written
    back to vancouver.json - position/rotation/justification (a new "center"
    anchor for KiCad's default), a deleted leader, an edited text (station
    "wrap" or label.short), moved city names. Art deleted by hand (SeaBus
    dashes, a route or boundary piece) is recorded as "suppressed_art" keys
    that export_art.py then leaves out; the art manifest now maps uuid->key.
    The user's first label pass (saved from KiCad 10, which also upgraded
    the board file to version 20260206) is imported: 63 label chan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
    [vancouver-skytrain-pcb-2026-09-07-user-edits.kicad_pcb]
2026-09-09 ai-v3: update ROW0-7 footprints from library; back-side mask exports
    tools/update_footprints.py replaces board footprints with their current
    library copies through KiCad 10's pcbnew API (no CLI exists for it),
    keeping placement, side, reference/value and custom fields (LCSC, MFG),
    schematic path and pad nets - nets assigned after the footprint joins
    the board, or they are lost. Clears the 7 lib_footprint_mismatch DRC
    items; the rest of DRC is unchanged (4 mounting-hole/water shorts, 2
    starved thermals, 2 unconnected). Includes the user's back-side routing
    and M3 mounting holes.
    test-results: board-bottom-mask.png (transparent, cropped to the
    outline, 10.62 px/mm), board-silhouette.png, boar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
    [vancouver-skytrain-pcb-2026-09-08-pre-fp-update.kicad_pcb]
2026-09-09 ai-v3: JLCPCB fabrication outputs
    hardware/jlcpcb/: gerbers (9 layers, Protel extensions, mask-subtracted
    silk) + Excellon drill and map zipped for the order page; BOM and CPL in
    JLC's column format for SMT assembly, covering the 68 WS2812B LEDs
    (C5349954) and 8 x 10uF 0402 (C52923) - switches are DNP, the XIAO is a
    hand-soldered module. tools/make_jlcpcb.py derives the two JLC files
    from kicad-cli's raw pos/BOM exports and builds the zip; README.md in
    the folder has the upload map and the exact commands.
    DRC at this state (KiCad 10.0.5): no unconnected items, no clearance /
    edge / courtyard violations; remaining are the two no-net mounting holes
    touching the water copper and two thin GND t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
    [bom-jlcpcb.csv, bom-raw.csv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]
2026-09-09 ai-v3: regenerate JLCPCB outputs from the current board
    [vancouver-skytrain-pcb-B_Cu.gbl, vancouver-skytrain-pcb-B_Mask.gbs, vancouver-skytrain-pcb-B_Paste.gbp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]
2026-09-09 docs: front and back board renders in the README
    KiCad 10 renders, transparent background cropped to the outline.
2026-09-17 ai-v3 firmware: XIAO ESP32-C3 target, and fix the LED/button pins
    The pin assignments were wrong for this board. Read back from the PCB
    with pcbnew, U1's pads go:
    pad 8 (D7) -> LED_IN, straight into LED1 DI (was assumed D0)
    pads 1-4 (D0..D3) -> BUTTON_01..04 / SW1..SW4 (were assumed D1..D4)
    So the data line was being driven from a button pin and the buttons read
    from pins that include the LED line. Fixed, and the stale comment about a
    74AHC1G125 level shifter is gone - v3 drives the chain directly from the
    XIAO at 3.3 V, with no shifter on the BOM.
    Adds an xiao_esp32c3 environment (default) alongside the RP2040 one; the
    D-numbered pin names map to the right GPIO per board, so the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
2026-10-10 docs: runbook for starting a new city, and refresh the stale READMEs
    runbook-new-city.md: the ten phases for doing this again in another city -
    scope, OSM station data, finding authoritative polygon hydrography, frame
    and board size, the data build, labels, hardware, fab, firmware, bring-up.
    Each phase says what carries over unchanged and what needs a city-specific
    version, with the gates to stop at (geography preview approved before any
    PCB work, DRC categories that must be zero, LED rotation checked before
    paying JLC). Linked from README.md and AGENTS.md.
    The two READMEs it points at had drifted and would have misled anyone
    following them: input/README.md still called build_from_osm.py th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
